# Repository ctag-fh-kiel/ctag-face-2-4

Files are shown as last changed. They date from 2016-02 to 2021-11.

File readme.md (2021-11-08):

CTAG face2|4 Audio Card, based on AD1938 codec
==============================================

This document includes board information, assembly guidelines, extensions and revision remarks, license and authors information.

Board information
-----------------
- 4 layer PCB including ground and power plane
- 10mil tracks offering close to 50Ohms impedance
- Part sizes on board are chosen to allow for hand-soldering 0603 as standard size for resistors etc.
- Used http://kicad.org/ for board design
- Board has 3 logical sections
  - Power supply (digital, analog)
     - Includes separate 3.3V digital supply and 3.3V + 5V analog supply
     - Includes boost converter that allows to run board on dual AA battery pack (3V input)
     - Standard input voltage at P201 should be +5V, see assembly options below
  - Codec including reset circuitry and digital I/O
  - Analog I/O
     - We checked several different single supply rail-to-rail OP Amps, where the cheap TLV272 performed pretty well, similar to the LMV722
- Codec and analog section is mainly based on Analog Devices reference design http://www.analog.com/media/en/technical-documentation/user-guides/UG-087.pdf

Assembly
-------------
- face2|4 BOM shared at Mouser
  - http://www.mouser.com/tools/projectcartsharing.aspx Access ID: 43007b9807
- Start with assembling the power supply sections
  - Several options for configuration are possible
     - A: Simplest possible, assemble only U203, U204, bypass U201 with JP201, bypass L202 with JP206, bypass L203 with JP207, assemble FB202, place JP204. Input voltage can be anything from 6-9V in this configuration.
     - B: No dedicated 3.3V digital do not assemble U202, assemble FB202, input voltage can be anything 2.4V-5V, boost converter will generate 5.5V for low-noise LDOs
     - C: With dedicated 3.3V digital supply, default in schematic, input voltage should be 5V
  - Check if power supply works by observing the LEDs
- Continue with codec, digital I/O and bias circuitry
  - Assembling only C311, C312 + JP301 is enough, using CM bias for test purposes
  - Test codec with microcontroller system, check at R602 R605 for signal output	
- Finally assemble analog section
  - May play around with some different OP amps

Extensions
-------------
- Created cape for Beagle Bone Green / Black including digital isolators to reduce noise (BBG-cape)
- Beagle Board X15 break out adapters for Hirose headers

Revisions
-------------
- face2|4
  - Rev. A2
     - Fixed polarity bug on IN2 at ADC2RP ADC2RN
    - Known Bugs: 
	 - none
	 - Rev. A has polarity bug on IN2
  - Todos for next Rev.
     - Possibly simplify power supply
     - Remove option to choose bias output from codec --> simplify board
	 - Option for balanced inputs
	 - Optimize pins on P1001 to improve routing, i.e. less vias on high speed digital lines, preserve impedance
- BBG-cape
  - Rev. A 
     - Initial Revision
    - Known Bugs: -
- X15 adaptor
  - Rev. A
     - Initial Revision, thanks to Michael Welling for review
	 
License
-------
This work is licensed under the Creative Commons Attribution-NonCommercial-ShareAlike 4.0 International License. 
To view a copy of this license, visit http://creativecommons.org/licenses/by-nc-sa/4.0/.
Anyone re-using this design needs to attribute to authors and http://www.creative-technologies.de website.

Authors
-------
- Robert Manzke (robert.manzke@fh-kiel.de), PCB Design
- Henrik Langer (henrik.langer@student.fh-kiel.de), Component Selection, Driver Development for Beagle Bone Series

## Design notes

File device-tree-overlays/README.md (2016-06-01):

# CTAG-face-2|4 - Device Tree Overlays
There are 3 different device tree overlays for 2, 4 and 8 audio channels.
Instructions for the build process can be found [here](https://github.com/beagleboard/bb.org-overlays).

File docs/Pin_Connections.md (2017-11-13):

## BeagleBone Black/Green <-> CTAG face2|4 Pin Connections 

| CTAG face2&#124;4 Pin Name | CTAG face2&#124;4 Pin No. |BB Black/Green Pin No. | BB Black/Green Mode Name | BB Black/Green Pin Name |
| --- |:---:|:---:| --- | --- |
| DLRCLK | 10 | P9.29 Mode 0 | mcasp0_fsx | SPI1_DO |
| DBCLK | 8 | P9.31 Mode 0 | mcasp0_aclkx | SPI1_SCLK |
| ALRCLK | 7 | P9.27 Mode 0 | mcasp0_fsr | GPIO3_19 |
| ABCLK | 9 | P9.12 Mode 6 | mcasp0_aclkr | GPIO1_28 |
| DSDATA1 | 18 | P9.28 Mode 2 | mcasp0_axr2 | SPI1_CS0 |
| ASDATA1 | 3 | P9.30 Mode 0 | mcasp0_axr0 | SPI1_D1 |
| spi4 | 17 | P9.17 Mode 0 | spi0_cs0 | I2C1_SCL |
| spi3 | 15 | P9.22 Mode 0 | spi0_sclk | UART2_RXD |
| spi2 | 13 | P9.21 Mode 0 | spi0_d0 | UART2_TXD |
| spi1 | 11 | P9.18 Mode 0 | spi0_d1 | I2C1_SDA |
| RESET_IN | 4 | P9.15 Mode 7 | gpio1[16] | GPIO1_16 |

## BeagleBone Black/Green <-> CTAG face2|4 SW SPI Pin Connections 

| CTAG face2&#124;4 Pin Name | CTAG face2&#124;4 Pin No. |BB Black/Green Pin No. | BB Black/Green Mode Name | BB Black/Green Pin Name |
| --- |:---:|:---:| --- | --- |
| DLRCLK | 10 | P9.29 Mode 0 | mcasp0_fsx | SPI1_DO |
| DBCLK | 8 | P9.31 Mode 0 | mcasp0_aclkx | SPI1_SCLK |
| DSDATA1 | 18 | P9.28 Mode 2 | mcasp0_axr2 | SPI1_CS0 |
| ASDATA1 | 3 | P9.30 Mode 0 | mcasp0_axr0 | SPI1_D1 |
| spi5 | TBD | P8.31 Mode 7 | spi_cs1 | GPIO0_10 |
| spi4 | TBD | P8.17 Mode 7 | spi_cs0 | GPIO0_27 |
| spi3 | TBD | P8.32 Mode 7 | spi_clk | GPIO0_11 |
| spi2 | TBD | P8.14 Mode 7 | spi_miso | GPIO0_26 |
| spi1 | TBD | P8.33 Mode 7 | spi_mosi | GPIO0_9 |
| RESET_IN | TBD | P8.34 Mode 7 | gpio2[17] | GPIO2_17 |

For details about the expansion connectors check the [BeagleBone Black System Reference Manual](https://github.com/CircuitCo/BeagleBone-Black/blob/master/BBB_SRM.pdf) p. 82 ff.

## BeagleBoard-X15 <-> CTAG face2|4 Pin Connections

| CTAG face2&#124;4 Pin Name | CTAG face2&#124;4 Pin No. | BB-X15 Pin No. | BB-X15 Pin Name | AM5728 Ball | Muxmode	| Offset | Signal	|
|:--- |:--- |:--- |:--- |:--- |:---|:--- |:---|
| DLRCLK | 10 		 | P17.52 	  | MCASP2_FSX | A18	  | 0		| 0x2F8	 | mcasp2_fsx	|
| DBCLK | 8 		 | P17.21 	  | MCASP2_ACLKX | A19	  | 0		| 0x2F4	 | mcasp2_aclkx	|
| ALRCLK | 7 		 | P17.57 	  | MCASP2_FSR | A20	  | 0		| 0x300	 | mcasp2_fsr	|
| ABCLK | 9 		 | P17.44 	  | MCASP2_ACLKR | E15	  | 0		| 0x2FC	 | mcasp2_aclkr	|
| DSDATA1 | 18 		 | P17.18 	  | MCASP2_AXR2 | C15	  | 0		| 0x30C	 | mcasp2_axr2	|
| ASDATA1 | 3 		 | P17.54 	  | MCASP2_AXR0 | B15	  | 0		| 0x304	 | mcasp2_axr0	|
| spi4	 | 17 		 | P16.3 	  | GPIO4_17	 | A12	  | 3		| 0x2E0	 | spi3_cs0	|
| spi3 | 15 		 | P16.34 	  | GPIO5_10	 | B12	  | 3		| 0x2D4	 | spi3_sclk	|
| spi2 | 13 		 | P16.33 	  | GPIO5_12	 | B13	  | 3		| 0x2DC	 | spi3_d0	|
| spi1 | 11 		 | P16.4 	  | GPIO5_11	 | A11	  | 3		| 0x2D8	 | spi3_d1	|
| RESET_IN | 4 		 | P17.25 	  | GPIO5_9 | D12	  | 14		| 0x2D0	 | gpio5_9	|

For details about the expansion connectors check out the [BeagleBoard-X15 Schematic](https://github.com/beagleboard/beagleboard-x15/blob/master/BeagleBoard-X15_RevA2.pdf?raw=true)
and [AM5728 datasheet](http://www.ti.com/lit/ds/symlink/am5728.pdf).

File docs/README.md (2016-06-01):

# Contents
+ [Quick Start Guide](https://github.com/ctag-fh-kiel/ctag-face-2-4/blob/master/docs/Quick_Start_Guide_Debian_Image.md) for SD Card Image
+ [Kernel Compilation Guide](https://github.com/ctag-fh-kiel/ctag-face-2-4/blob/master/docs/Kernel_Compilation_Guide.md) for BeagleBone Black/Green
+ [Manual](https://github.com/ctag-fh-kiel/ctag-face-2-4/blob/master/docs/Automatic_Evaluation_Manual.md) for Automatic Evaluation
+ BeagleBone Black/Green <-> CTAG face2|4 Audio Card [Pin Connections Table](https://github.com/ctag-fh-kiel/ctag-face-2-4/blob/master/docs/Pin_Connections.md)

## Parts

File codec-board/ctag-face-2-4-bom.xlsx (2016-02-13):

Mouser | Id | Designator | Package | Quantity | Designation | MfrNum | Remarks
x | 1 | C509,C204,C405,C409,C505,C603,C607,C703,C707,C803,C807,C903,C907 | c_elec_6.3x5.7 | 13 | 47uF | EEE-FC1C470P | Panasonic FC Type
x | 2 | C201 | C_0603_HandSoldering | 1 | 33pF | VJ0603A330JXACW1BC
x | 3 | C202 | C_1210_HandSoldering | 1 | 22uF | C3225X7R1C226K250AC | 10% X7R Highest Voltage Type possible
x | 4 | C203,C205,C207,C208,C209,C210,C211,C212,C213,C214,C215,C216 | C_1210_HandSoldering | 12 | 10uF | GRM32DR71E106KA12L | 10% X7R Highest Voltage Type possible
x | 5 | C206 | TantalC_SizeA_EIA-3216_HandSoldering | 1 | 100uF | TCNK107M006R0200
x | 6 | C301,C302,C303,C304,C305,C309,C311,C314,C401,C410,C413,C420,C501,C510,C513,C520,C602,C702,C802,C902 | C_0603_HandSoldering | 20 | 100nF | C0603C104K5RACTU
x | 7 | C306 | C_0603_HandSoldering | 1 | 390pF | GRM1885C1H391JA01D
x | 8 | C307 | C_0603_HandSoldering | 1 | 5,6nF | C0603C562J5GACTU
x | 9 | C308,C313 | C_0603_HandSoldering | 2 | 22pF | C0603C220J5GACTU
x | 10 | C310,C312 | c_elec_4x5.7 | 2 | 10uF | EEE-FC1C100R
x | 11 | C402,C404,C414,C416,C502,C504,C514,C516 | C_0805_HandSoldering | 8 | 10uF | GRM21BR71A106KA73L
x | 12 | C403,C411,C412,C415,C503,C511,C512,C515 | C_0603_HandSoldering | 8 | 100pF | C0603C101J5GACTU
x | 13 | C406,C417,C506,C517,C601,C606,C701,C706,C801,C806,C901,C906 | C_0603_HandSoldering | 12 | 270pF | GRM1885C1H271JA01D
x | 14 | C407,C408,C418,C419,C507,C508,C518,C519 | C_0603_HandSoldering | 8 | 1nF | GCM188R71H102KA37D
x | 15 | C604,C608,C704,C708,C804,C808,C904,C908 | C_0603_HandSoldering | 8 | 200pF | GRM1885C2A201JA01D
x | 16 | C605,C609,C705,C709,C805,C809,C905,C909 | C_0603_HandSoldering | 8 | 3,3nF | C0603C332K5RACTU
x | 17 | D201 | SOD-123 | 1 | D_Schottky | STPS140Z
x | 18 | D203 | LED-1206 | 1 | LED3V3D | SML-LX1206GC-TR1
x | 19 | D204 | LED-1206 | 1 | LED3V3A | SML-LX1206GC-TR1
x | 20 | D205 | LED-1206 | 1 | LED5VA | SML-LX1206GC-TR1
x | 21 | JP201,JP206,JP207 | R_0805_HandSoldering | 3 | Jumper_NO_Small | RC0805JR-070RL
x | 22 | JP203,JP204,JP301,JP302 | R_0603_HandSoldering | 4 | Jumper_NO_Small | ERJ-3GEY0R00V
x | 23 | R201 | R_0603_HandSoldering | 1 | 115k | ERJ-3EKF1153V | Resistors all probably 1%, except digital section
x | 24 | R202,R303 | R_0603_HandSoldering | 2 | 1M | ERJ-3EKF1004V
x | 25 | R203 | R_0603_HandSoldering | 1 | 32k4 | ERJ-3EKF3242V
x | 26 | R204,R206 | R_0603_HandSoldering | 2 | 270 | ERJ-3EKF2700V
x | 27 | R205,R207,R302,R305,R408,R409,R508,R509,R604,R608,R704,R708,R804,R808,R904,R908 | R_0603_HandSoldering | 16 | 100k | ERJ-3EKF1003V
x | 28 | R208 | R_0603_HandSoldering | 1 | 620 | ERJ-3EKF6200V
x | 29 | R301 | R_0603_HandSoldering | 1 | 562 | ERJ-3EKF5620V
x | 30 | R304 | R_0603_HandSoldering | 1 | 100 | ERJ-3EKF1000V
x | 31 | R401,R402,R410,R411,R501,R502,R510,R511 | R_0603_HandSoldering | 8 | 237 | ERJ-3EKF2370V
x | 32 | R403,R404,R405,R406,R407,R412,R413,R414,R503,R504,R505,R506,R507,R512,R513,R514,R601,R602,R605,R606,R701,R702,R705,R706,R801,R802,R805,R806,R901,R902,R905,R906 | R_0603_HandSoldering | 32 | 5k36 | ERJ-3EKF5361V
x | 33 | R603,R607,R703,R707,R803,R807,R903,R907 | R_0603_HandSoldering | 8 | 301 | ERJ-3EKF3010V
x | 34 | R1001,R1002,R1003,R1004,R1005,R1006,R1007,R1008,R1009,R1010 | R_0603_HandSoldering | 10 | 51 | ERJ-3EKF51R0V
x | 35 | SW301 | SW_SPST_PTS645 | 1 | SW_PUSH | PTS645SM43SMTR 92 LFS
x | 36 | U201 | MSOP-8_3x3mm_Pitch0.65mm | 1 | MCP1642B-ADJI/MS | MCP1642B-ADJI/MS
x | 37 | U202 | SOT-223 | 1 | TLV1117 | TLV1117-33IDCYR
x | 38 | U203 | SOIC-8_3.9x4.9mm_Pitch1.27mm | 1 | ADP7102ARDZ-3.3-R7 | ADP7102ARDZ-3.3-R7
x | 39 | U203,U204 | SOIC-8_3.9x4.9mm_Pitch1.27mm | 1 | ADP7102ARDZ-5.0-R7 | ADP7102ARDZ-5.0-R7
x | 40 | U301 | LQFP-48_7x7mm_Pitch0.5mm | 1 | AD1938 | AD1938YSTZ
x | 41 | U302 | SOT-143 | 1 | ADM811TARTZ | ADM811TARTZ-REEL7
x | 42 | U401,U402,U501,U502,U601,U701,U801,U901 | SOIC-8_3.9x4.9mm_Pitch1.27mm | 8 | 2CH-OPAMP | LME49721MAX/NOPB
x | 43 | Y301 | Q_49U3HMS | 1 | 24,576MHz | AT-24.576MAGK-T | Alternative
x | 44 | Y301 | Q_49U3HMS | 1 | 12,288MHz | AT-12.288MAGE-T
x | 45 | D202 | Diode-Universal-SMA-SMB_Handsoldering | 1 | FM4002 | FM4002
x | 46 | FB201,FB203 | R_0805_HandSoldering | 2 | 330R | 742792037 | Würth Beads
x | 47 | FB202 | R_0805_HandSoldering | 1 | 600R | 742792040
x | 48 | L201,L202,L203 | LPS4018 | 3 | 4.7uH | LPS4018-472MRC
x | 49 | P307 | DIL Socket 4+4 | 1 | ~ | M20-7830446 (https://www.mouser.de/Search/ProductDetail.aspx) | Reichelt
x | 50 |  | Stiftleiste 40 Pins RM2,54 | 1 |  | M20-9734045 (https://www.mouser.de/Search/ProductDetail.aspx)
x | 51 |  | DIL Socket 10+10 | 1 |  | M20-7831046 (https://www.mouser.de/Search/ProductDetail.aspx)
x | 52 | C207, C208, C213, C214 | Alternative Configuration | 4 | 1uF | GRM32RR71H105KA01L | Configuration according to data sheet of ADPxxx
x | 53 | R604, R608 etc. | Alternative Configuration | 8 | 49k9 | ERJ-3EKF4992V

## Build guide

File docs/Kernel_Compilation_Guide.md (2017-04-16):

# BeagleBone Green/Black Kernel Compilation Guide

*The build instructions were tested on Ubuntu 14.04.*

+ Install build tools
```bash
sudo apt-get install git lzop libssl-dev libncurses5-dev wget u-boot-tools git
```
+ Clone Git repository of forked Linux kernel
```bash
git clone https://github.com/henrix/beagle-linux.git && cd beagle-linux
```
+ Download hard float linearo compiler
```bash
wget https://releases.linaro.org/components/toolchain/binaries/5.4-2017.01/arm-linux-gnueabihf/gcc-linaro-5.4.1-2017.01-x86_64_arm-linux-gnueabihf.tar.xz
tar xf gcc-linaro-5.4.1-2017.01-x86_64_arm-linux-gnueabihf.tar.xz
```
+ Clean build directory and create temporary directory
```bash
make mrproper && mkdir modules_tmp
```
+ Generate kernel config
```bash
make ARCH=arm CROSS_COMPILE=gcc-linaro-5.4.1-2017.01-x86_64_arm-linux-gnueabihf/bin/arm-linux-gnueabihf- bb.org_defconfig
```
+ Enable driver for CTAG face2|4 Audio Card (→ Device Drivers → Sound card support → Advanced Linux Sound Architecture → ALSA for SoC audio support → SoC Audio Support for CTAG face-2-4 Audio Card (AD1938))
```bash
make ARCH=arm CROSS_COMPILE=gcc-linaro-5.4.1-2017.01-x86_64_arm-linux-gnueabihf/bin/arm-linux-gnueabihf- menuconfig
```
+ Compile the kernel
```bash
make ARCH=arm CROSS_COMPILE=gcc-linaro-5.4.1-2017.01-x86_64_arm-linux-gnueabihf/bin/arm-linux-gnueabihf- -j9
```
+ Compile device tree blobs
```bash
make ARCH=arm CROSS_COMPILE=gcc-linaro-5.4.1-2017.01-x86_64_arm-linux-gnueabihf/bin/arm-linux-gnueabihf- dtbs -j9
```
+ Compile kernel modules
```bash
make ARCH=arm CROSS_COMPILE=gcc-linaro-5.4.1-2017.01-x86_64_arm-linux-gnueabihf/bin/arm-linux-gnueabihf- modules -j9
```
+ Install compiled kernel and modules to temporary directory
```bash
make ARCH=arm CROSS_COMPILE=gcc-linaro-5.4.1-2017.01-x86_64_arm-linux-gnueabihf/bin/arm-linux-gnueabihf- INSTALL_MOD_PATH=modules_tmp modules_install
```
+ Copy kernel image to SD card
```bash
sudo cp arch/arm/boot/zImage /media/$USER/rootfs/boot/vmlinuz-4.1.18+
```
+ Copy kernel modules to SD card
```bash
sudo cp -r modules_tmp/lib/ /media/$USER/rootfs/
```
+ Copy device tree blobs to SD card
```bash
sudo mkdir -p /media/$USER/rootfs/boot/dtbs/4.1.18+ && cp -r arch/arm/boot/dts/*.dtb /media/$USER/rootfs/boot/dtbs/4.1.18+/
```
+ Copy kernel configuration to SD card
```bash
sudo cp .config /media/$USER/rootfs/boot/config-4.1.18+
```
## The next steps must be executed directly on the BeagleBone Black/Green
+ Insert the following line into **/boot/uEnv.txt** to use the new kernel
```bash
uname_r=4.1.18+
```
+ Insert the following line into **/boot/uEnv.txt** to use the custom device tree blob
```bash
dtb=am335x-bonegreen-ctag-face.dtb
```
+ Reboot to use new kernel
```bash
reboot
```
+ Generate initramfs image and reboot again
```bash
sudo update-initramfs -c -k $(uname -r)
reboot
```
+ Clone CTAG face2|4 AudioCard repo
```bash
git clone https://github.com/ctag-fh-kiel/ctag-face-2-4.git && cd ctag-face-2-4/device-tree-overlays
```
+ Compile Device Tree Overlays for CTAG face2|4 Audio Card
```bash
dtc -O dtb -o BB-CTAG-FACE-8CH-00A0.dtbo -b 0 -@ BB-CTAG-FACE-8CH-00A0.dts
sudo mv BB-CTAG-FACE-8CH-00A0.dtbo /lib/firmware
```
+ Load kernel modules for CTAG face2|4 Audio Card with Bone-Cape-Manager
```bash
sudo sh -c "echo 'BB-CTAG-FACE-8CH' > /sys/devices/platform/bone_capemgr/slots"
```

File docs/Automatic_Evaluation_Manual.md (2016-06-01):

# Manual for Automatic Evaluation

## Test Prerequisites
+ ADC1 needs to be connected with DAC1 (loopback)
+ GNU Octave Version>3.8 (already installed on SD card image)

## Description
The automatic evaluation is made up of 4 single tests for:

1. Latency (took from [alsa-lib](http://www.alsa-project.org/alsa-doc/alsa-lib/_2test_2latency_8c-example.html))
2. THD, THD+N, DNR
3. Crosstalk
4. Frequency Response

The test scripts and sample files are located in the directory **/home/debian/automated_test** on the SD card image.<br>
The automatic evaluation can be executed by running
```bash
automated_test.sh
```
from the home directory of user "debian".

## BASH script parameters
1. ALSA Playback Device (e.g. hw:0)
2. ALSA Capture Device
3. Name of soundcard to be tested (will be used in spectrum plots)
4. *Name of single test (latency, thd, crosstalk, frequency-response) (optional)*

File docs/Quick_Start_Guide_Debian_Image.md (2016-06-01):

# Quick Start Guide for SD Card Image 
## SD Card Preparation
1. Download [Debian Wheezy SD card image](https://drive.google.com/file/d/0B2goLqs_HZ3QMFV4SFNySjJzX3M/view?usp=sharing)
2. Install Debian image on SD card (see [Raspberry Pi Guide](https://www.raspberrypi.org/documentation/installation/installing-images/README.md))

## Debian Configuration of SD Card Image
### Login 
Username: debian <br>
Password: temppwd

### Global Soundcard Configuration
The required kernel modules will be loaded automatically at boot time (see /etc/rc.local).<br>
By default the soundcard is configured to use 4 input channels and 8 output channels.<br>
If a higher sampling rate of 192 kHz is needed, the soundcard can be configured to use only 4 output channels.<br>
(Change line 22 in /etc/rc.local<br>**sh -c "echo 'BBB-AD193X-8TDM' > /sys/devices/platform/bone_capemgr/slots"** to<br>**sh -c "echo 'BBB-AD193X-4TDM' > /sys/devices/platform/bone_capemgr/slots"**)<br>
The global ALSA configuration /etc/asound.conf contains routings to interact with single ADCs and DACs (ADC1 - ADC2, DAC1 - DAC4)

### Soundcard Control
The multichannel soundcard can be controlled with the ALSA tools "alsamixer" or "amixer".
alsamixer has a dialog based GUI and is simpler, but amixer is more detailed.
The soundcard offers different playback de-emphasis modes, ADC high pass filter configuration and volume controls for single ADCs and DACs.

### Automatic Evaluation
The scripts for the automatic evaluation of the audio system are located in /home/debian/automated_test.
The results will be saved in /home/debian/automated_test/results.
See the [Manual for Automatic Evaluation](https://github.com/ctag-fh-kiel/ctag-face-2-4/blob/master/docs/Automatic_Evaluation_Manual.md) for more details.

### Demo Surround-Delay Audio Effect
The Surround-Delay effect can be executed by running the following command from the home directory of user "debian":
```bash
./delay.sh
```

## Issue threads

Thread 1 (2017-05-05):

Kernel compilation error

Eldarosaurus, 2017-05-05:
I'm trying to compile the kernel for a Beaglebone Black Wireless on a Ubuntu 14.04 machine. When trying to compile the kernel I get this error:

Makefile:660: Cannot use CONFIG_CC_STACKPROTECTOR_STRONG: -fstack-protector-strong not supported by compiler

Any ideas on what is going wrong?

I've also tried the quick setup SD image, but my Beaglebone Black Wireless won't boot with that image...

henrix, 2017-05-06:
Did you use a recent version of Linaro compiler (see [here](https://github.com/ctag-fh-kiel/ctag-face-2-4/blob/master/docs/Kernel_Compilation_Guide.md)).
Furthermore, the driver is already included in the official BeagleBoard.org images, so you don't have to compile the kernel on yourself.

Eldarosaurus, 2017-05-06:
So if I install an official BeagleBoard.org image, I can use the functions of the AD1938 out of the box with the commands described on this repository?

Is that correct?

henrix, 2017-05-07:
Have you generated a buildconfig (bb.org_defconfig) before compilation?
I just checked it and I don't get those errors.

Yes, after you flashed a recent image to a SD-card, you have to set the base device tree in /boot/uEnv.txt (dtb=am335x-bonegreen-ctag-face.dtb) and compile the appropriate device tree overlay (e.g. BB-CTAG-FACE-8CH-00A0.dts) from this repo using device tree compiler (e.g. dtc -O dtb -o BB-CTAG-FACE-8CH-00A0.dtbo -b 0 -@ BB-CTAG-FACE-8CH-00A0.dts) and move it to /lib/firmware as described in the [kernel compilation guide](https://github.com/ctag-fh-kiel/ctag-face-2-4/blob/master/docs/Kernel_Compilation_Guide.md).

Then you can simply load the overlay and the soundcard is showed up with aplay -l.

Eldarosaurus, 2017-05-08:
Yes I did, I just repeated all of the steps and at one point I got a prompt to install this thing: 'sudo apt-get install tor-arm', which I did. Then I ran the entire routine again and surely the error message was gone on the first compilation command, but afterwards, my terminal started throwing other errors. For future reference/improvement/fixing I'll attach the full terminal conversation to this post, but at this time, I'll be moving on using an official BeagleBoard.org image.

[Full output.txt](https://github.com/ctag-fh-kiel/ctag-face-2-4/files/983086/Full.output.txt)

Closed 2017-05-08.

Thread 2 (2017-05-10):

Beaglebone Black Wireless fails to boot after custom device tree blob change

Eldarosaurus, 2017-05-10:
Let's start this issue where the other one ended: I'm trying to get the AD1938 working with a BeagleBone Black Wireless. I flashed the BBBW with a recent official BBBW image and tried to use the custom device tree blob presented in this repository. However after changing uEnv.txt my BBBW refuses to boot.

When adding/substituting (I tried both) this line:
`dtb=am335x-bonegreen-ctag-face.dtb`
The BBB won't boot and gets stuck with the usr0 led blinking

I get the same thing when using the given quick start image by the way.

When adding/substituting (I tried both) this line as well as the above:
`uname_r=4.1.18+`
The BBB won't boot and gets stuck with all usr leds on forever.

I first tried to do these adaptations with the OS on the SD-card. Then I also tried to copy the OS to the internal memory first and then doing the adaptations, but (as expected) no change there, so that's not the issue.

Any ideas on what's going wrong?
How long should I wait with the led blinking until giving up, my last attempt ran for an hour and a half... What's the booting time of a working solution?

henrix, 2017-05-11:
I think this is caused from the device tree.
I will create a new device tree for the BeagleBone Black Wireless the next days, but unfortunately I don't have a BBB Wireless for testing.

I will update this thread then and hope it works.

Moreover I will create a stable 4.4 branch and move my active development for the daisy chained driver to a dedicated branch.

Eldarosaurus, 2017-05-11:
That's very good news.

I'll be using a BeagleBone Black (non Wireless) in the meantime - or do you recommend the Green?

(To clarify: I'm using an AD1938 as a part of my master's thesis and I'm trying to find a good platform to demo my hardware ;) )

henrix, 2017-05-12:
You could use the Black or Green.
Both are working fine.

Glad to hear that you use our platform;)

Eldarosaurus, 2017-05-23:
Hi, I've tried both the Black and Green but to no avail.

The quick start image still won't boot and when using a beagleboard.org image, the black behaves in the same way as the black wireless and the green won't even boot with the unmodified image. Surely I must be doing something wrong. Could you give a more detailed description of the steps that need to be taken? I hope I'm making a small mistake here ;)

henrix, 2017-05-23:
Hi,

I have created a [new image](https://drive.google.com/file/d/0B2goLqs_HZ3QRXdhWno2cUsta0U/view?usp=sharing) last week. You don't have to change anything, to use it with the AD1938 codec.

On the official images, you have to:
1. Edit the dtb= line in the uEnv.txt file and change it to am335x-boneblack-ctag-face.dtb or am335x-bonegreen-ctag-face.dtb
2. Compile the device tree overlay (either the overlays for software SPI or hardware SPI) and load it via the Bone Capemanager

> How do you interface with the boards: USB, Ethernet, HDMI & Keyboard (in the case of the BBB)...?

I personally use the virtual Ethernet via USB and ssh due to flexibility.

> When used with USB, which computer do you use? (I've tried on a windows laptop and a macbook)

I'm using a Linux distribution. If you want to use Windows or Mac OS, you have to [install the drivers](http://beagleboard.org/getting-started) for virtual Ethernet.

> When used with ethernet, are there special connection steps to be taken?

The Ethernet port of the BB is configured to use an automatically assigned IP. So you need a DHCP server.

> When used with HDMI, does your BBB give a terminal window when connected to a screen?

I don't use HDMI. In our device tree, HDMI is disabled, as well.

> How long does it take for the quickstart image to boot?

It should be around 20 seconds (depends if you are using a GUI or running the BB headless). Moreover there are some performance optimizations available.

> Update: when using the quickstart image on SD in a BBB, connected via Ethernet, my windows computer's network troubleshooter says that "Ethernet does not have a valid IP configuration"

You don't have a DHCP server running. You can try [this one](http://www.dhcpserver.de/cms/) on Windows.

Eldarosaurus, 2017-05-24:
Thanks for the answers!

I've been trying and searching around and here's where I am now:
I did install all drivers but the DHCP seems to do things beyond my comprehension...

- On windows, I installed a DHCP server and I do get a connection, but when I try to ssh to the given IP address with putty, I get a connection timed out error, I also tried the default IP adresses, but to no good
- On linux (Ubuntu 14.04) , two Beaglebone virtual ethernet connections are active, but the same problem, I can't find the right IP address, tried nmap for a ton of addresses, but no luck there...

Which brings me to the next question:

Given that the Beaglebone gets it's IP address dynamically with DHCP, where can I find the right IP address for SSH? Or what's the name of the BBB for SSH (e.g. ssh debian@beaglebone doesn't work)?

Many thanks!

henrix, 2017-05-24:
The Ethernet port of the BeagleBone is configured to use a DHCP server by default.
The virtual Ethernet port via USB of the BeagleBone has a static IP (192.168.7.2) and should assign 192.168.7.1 to the virtual Ethernet port of your host PC.
So, when using the virtual Ethernet via USB, you should be able to ssh into your BeagleBone with `ssh debian@192.168.7.2` and the default password "temppwd".

Eldarosaurus, 2017-05-25:
Unfortunately, when connected with USB, all platform give a connection timeout for `ssh debian@192.168.7.2`. But I cracked it on windows. After setting up my DHCP server, I went into the networks and sharings center and changed the IP address for the windows computer for communicating via ipv4 to 192.168.7.1.

 https://www.youtube.com/watch?v=D-NEPiZDSx8 → it's shown in the middle of the video

Thanks for all the help :) let's hope I get everything running now :)

Closed 2017-05-25.

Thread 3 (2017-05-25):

Capture channels in amixer

Eldarosaurus, 2017-05-25:
I've made great progress :)

My custom hardware gets recognised, but the amixer command yields some surprising settings.

How are the capture channels configured? I'm getting two ADC's as expected, but they seem to be configured as playback channels and the four DAC channels seem to be configured as both playback and capture channels.

Is this normal?

Also, all inputs and outputs seem to be permanently off, I've tried changing this with numid cset ... but my commands seem to be ignored... What is the regular way to make these work? Might be a fault in my hardware too ;)

henrix, 2017-05-25:
Yes, that's a bit strange of alsamixer, but you can ignore it.
You can unmute the single ADCs and DACs with amixer (e.g. amixer -c 0 sset DAC1 on).

Eldarosaurus, 2017-05-27:
So should I ignore the playback/capture labels of the ADC1 en ADC2 and record using the DAC capture thingies?

Eldarosaurus, 2017-05-28:
Also do you recognise this error:

`arecord: pcm_read:2031: read error: Input/output error` when trying to record...

+ When I try to activate an ADC or a DAC, my command is processed, my terminal shows that the switch is on, but when I run `amixer` again, it's already back off again... Has this happened to you at some point?

henrix, 2017-05-29:
Ignore the playback/capture labels. The names are correct (e.g. ADC1 corresponds to the first hardware ADC). Maybe you have some SPI issues. You can check the kernel logs (my driver logs the register contents of the codec) for verification.

Eldarosaurus, 2017-05-29:
I am indeed having SPI connection issues, I hooked the board up to an oscilloscope and the SPI lines are all high (except the Cout one, which is 0), but no commands are executed, no matter which command I run, the lines stay high. Are there additional steps to be taken to activate the SPI-connection? Something with pin modes? I'm pretty new to linux... I'll take a look at those kernel logs.

henrix, 2017-05-30:
No, the pin modes are configured with the device tree overlay. Do you use the hardware SPI interface or software spi (spi-gpio)? If you playback or capture something, there should be something happening on the SPI interface (e.g. speaker-test).

Eldarosaurus, 2017-05-30:
My SPI wires are connected to pins 17, 18, 21 and 22, so I guess I'm using hardware SPI. (Right?) I'm trying to write to the SPI port now using Adafruit_BBIO, just to see if I can connect to the codec.

Eldarosaurus, 2017-05-30:
The kernel log revealed these errors:

`May  7 14:48:06 beaglebone kernel: [ 1105.814310] bone_capemgr bone_capemgr: part_number 'BB-CTAG-SW-8CH', version 'N/A'
May  7 14:48:06 beaglebone kernel: [ 1105.814362] bone_capemgr bone_capemgr: slot #4: override
May  7 14:48:06 beaglebone kernel: [ 1105.814386] bone_capemgr bone_capemgr: Using override eeprom data at slot 4
May  7 14:48:06 beaglebone kernel: [ 1105.814412] bone_capemgr bone_capemgr: slot #4: 'Override Board Name,00A0,Override Manuf,BB-CTAG-$
May  7 14:48:06 beaglebone kernel: [ 1105.840617] bone_capemgr bone_capemgr: slot #4: dtbo 'BB-CTAG-SW-8CH-00A0.dtbo' loaded; overlay i$
May  7 14:48:06 beaglebone kernel: [ 1105.938200] spi_gpio spi_gpio: can't setup spi32766.0, status -16
May  7 14:48:06 beaglebone kernel: [ 1105.944462] spi_master spi32766: spi_device register error /spi_gpio/ad193x@0
May  7 14:48:06 beaglebone kernel: [ 1105.966636] snd_ctag_face_2_4 ocp:sound: using only one audio codec (no daisy chain).
May  7 14:48:06 beaglebone kernel: [ 1105.966730] snd_ctag_face_2_4 ocp:sound: mclk not found.
May  7 14:48:06 beaglebone kernel: [ 1105.966786] snd_ctag_face_2_4 ocp:sound: ASoC: CODEC DAI ad193x-hifi not registered
May  7 14:48:06 beaglebone kernel: [ 1105.974688] snd_ctag_face_2_4 ocp:sound: snd_soc_register_card failed (-517)
May  7 14:48:06 beaglebone kernel: [ 1106.024593] spi_master spi32766: Failed to create SPI device for /spi_gpio/ad193x@0
May  7 14:48:06 beaglebone kernel: [ 1106.066220] snd_ctag_face_2_4 ocp:sound: using only one audio codec (no daisy chain).
May  7 14:48:06 beaglebone kernel: [ 1106.066314] snd_ctag_face_2_4 ocp:sound: mclk not found.
May  7 14:48:06 beaglebone kernel: [ 1106.066373] snd_ctag_face_2_4 ocp:sound: ASoC: CODEC DAI ad193x-hifi not registered
May  7 14:48:06 beaglebone kernel: [ 1106.074249] snd_ctag_face_2_4 ocp:sound: snd_soc_register_card failed (-517)`

Any idea?

Eldarosaurus, 2017-05-30:
The kernel log revealed some errors..

`May  7 14:48:06 beaglebone kernel: [ 1105.814310] bone_capemgr bone_capemgr: part_number 'BB-CTAG-SW-8CH', version 'N/A'`
`May  7 14:48:06 beaglebone kernel: [ 1105.814362] bone_capemgr bone_capemgr: slot #4: override`
`May  7 14:48:06 beaglebone kernel: [ 1105.814386] bone_capemgr bone_capemgr: Using override eeprom data at slot 4`
`May  7 14:48:06 beaglebone kernel: [ 1105.814412] bone_capemgr bone_capemgr: slot #4: 'Override Board Name,00A0,Override Manuf,BB-CTAG-$`
`May  7 14:48:06 beaglebone kernel: [ 1105.840617] bone_capemgr bone_capemgr: slot #4: dtbo 'BB-CTAG-SW-8CH-00A0.dtbo' loaded; overlay i$`
`May  7 14:48:06 beaglebone kernel: [ 1105.938200] spi_gpio spi_gpio: can't setup spi32766.0, status -16`
`May  7 14:48:06 beaglebone kernel: [ 1105.944462] spi_master spi32766: spi_device register error /spi_gpio/ad193x@0`
`May  7 14:48:06 beaglebone kernel: [ 1105.966636] snd_ctag_face_2_4 ocp:sound: using only one audio codec (no daisy chain).`
`May  7 14:48:06 beaglebone kernel: [ 1105.966730] snd_ctag_face_2_4 ocp:sound: mclk not found.`
`May  7 14:48:06 beaglebone kernel: [ 1105.966786] snd_ctag_face_2_4 ocp:sound: ASoC: CODEC DAI ad193x-hifi not registered`
`May  7 14:48:06 beaglebone kernel: [ 1105.974688] snd_ctag_face_2_4 ocp:sound: snd_soc_register_card failed (-517)`
`May  7 14:48:06 beaglebone kernel: [ 1106.024593] spi_master spi32766: Failed to create SPI device for /spi_gpio/ad193x@0`
`May  7 14:48:06 beaglebone kernel: [ 1106.066220] snd_ctag_face_2_4 ocp:sound: using only one audio codec (no daisy chain).`
`May  7 14:48:06 beaglebone kernel: [ 1106.066314] snd_ctag_face_2_4 ocp:sound: mclk not found.`
`May  7 14:48:06 beaglebone kernel: [ 1106.066373] snd_ctag_face_2_4 ocp:sound: ASoC: CODEC DAI ad193x-hifi not registered`
`May  7 14:48:06 beaglebone kernel: [ 1106.074249] snd_ctag_face_2_4 ocp:sound: snd_soc_register_card failed (-517)`

Eldarosaurus, 2017-05-30:
The kernel log did reveal some errors, they are in the image below...

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

henrix, 2017-05-30:
Have a look in the [pin connections table](https://github.com/ctag-fh-kiel/ctag-face-2-4/blob/master/docs/Pin_Connections.md). You are using the hardware SPI interface, so you have to use the [BB-CTAG-FACE-8CH overlay](https://github.com/ctag-fh-kiel/ctag-face-2-4/blob/master/device-tree-overlays/BB-CTAG-FACE-8CH-00A0.dts).

Eldarosaurus, 2017-05-30:
Right! And I'm trying to load the SW-overlay. Well that wouldn't work indeed.

Well, I just tried changing that, but when running

`sudo sh -c "echo 'BB-CTAG-FACE-8CH' > /sys/devices/platform/bone_capemgr/slots"`

This error comes up:

sh: echo: I/O error

Or am I doing that wrong? When I rebooted, the BB still tried to load the SW-overlay.

Or should I just change the pin configuration I'm using to the other one? In that case, what is the difference between spi4 and spi5?

Eldarosaurus, 2017-05-30:
Oh, I fixed the error, I had to remove the SW-overlay first in capemgr:

`sudo sh -c "echo '-4' > /sys/devices/platform/bone_capemgr/slots"`

henrix, 2017-05-30:
I think there is any issue in the Cape manager. If you are using my image, you should disable the automatic loading of the SW SPI overlay and load the BB-CTAG-FACE-8CH instead.

Eldarosaurus, 2017-05-30:
I've tried to do so, but my changes seem to be reversed immediately... Is my code in the previous messages correct?

henrix, 2017-05-30:
You remove overlays from the Cape manager with your code above.
Have a look in /etc/rc.local and change `BB-CTAG-SW-8CH` to `BB-CTAG-FACE-8CH`.

Eldarosaurus, 2017-05-30:
Well, I did those things now, the good news is: when running `cat /sys/devices/platform/bone_capemgr/slots`, BB-CTAG-SW-8CH is no longer loaded at boot.

The bad news is: BB-CTAG-FACE-8CH doesn't load in int's place and in the kernel logs, the errors remain the same

henrix, 2017-05-30:
Ok, can you please show your kernel logs regarding the sound drivers?

Eldarosaurus, 2017-05-31:
It works!

It was a hardware thing. I was searching around in the lab and found that the PCB track connected to the PD/RST pin was broken. I fixed it and now the interface works :)

Many thanks for the help!

But before closing the subject entirely, I'm recording, I turned on the ADC's but the recorded file is still empty, it must be something small, I measured my codec's inputs and I'm putting a 440 Hz wave on there..

Eldarosaurus, 2017-05-31:
Oddly enough, in the kernel logs, the BB is still trying to lode the software overlay

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

Eldarosaurus, 2017-05-31:
This is the kern.log file for my last bootup

[log.txt](https://github.com/ctag-fh-kiel/ctag-face-2-4/files/1041379/log.txt)

henrix, 2017-05-31:
The issue with the several files is regarded to alsalib. Have a look [here](https://superuser.com/questions/583826/recording-using-arecord-creates-thousands-of-files) how to avoid this.

Closed 2018-02-09.

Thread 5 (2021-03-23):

Different board designs?

resynth, 2021-03-23:
I'm trying to work out how to setup a CTAG face cape (as sold by Bela) in a non-standard way.  As my enclosure does not have space to stack the boards I wish to mount side by side with connectors between the headers of the Beaglebone Black and the headers of the CTAG face cape.  To do this I require a pin out or schematic for the CTAG face.
The CTAG hackaday page directed me here but after getting confused over the schematic it seems the files here relate to a different board or an older revision.  Is that the case?
I've been looking but this github repo is all I can find, are the drawings for the newer board somewhere else or are they closed source?

ctag-fh-kiel, 2021-03-23:
You can find it here: https://github.com/ctag-fh-kiel/bela-ctag

resynth, 2021-03-23:
Brilliant, thankyou

Closed 2021-06-10.

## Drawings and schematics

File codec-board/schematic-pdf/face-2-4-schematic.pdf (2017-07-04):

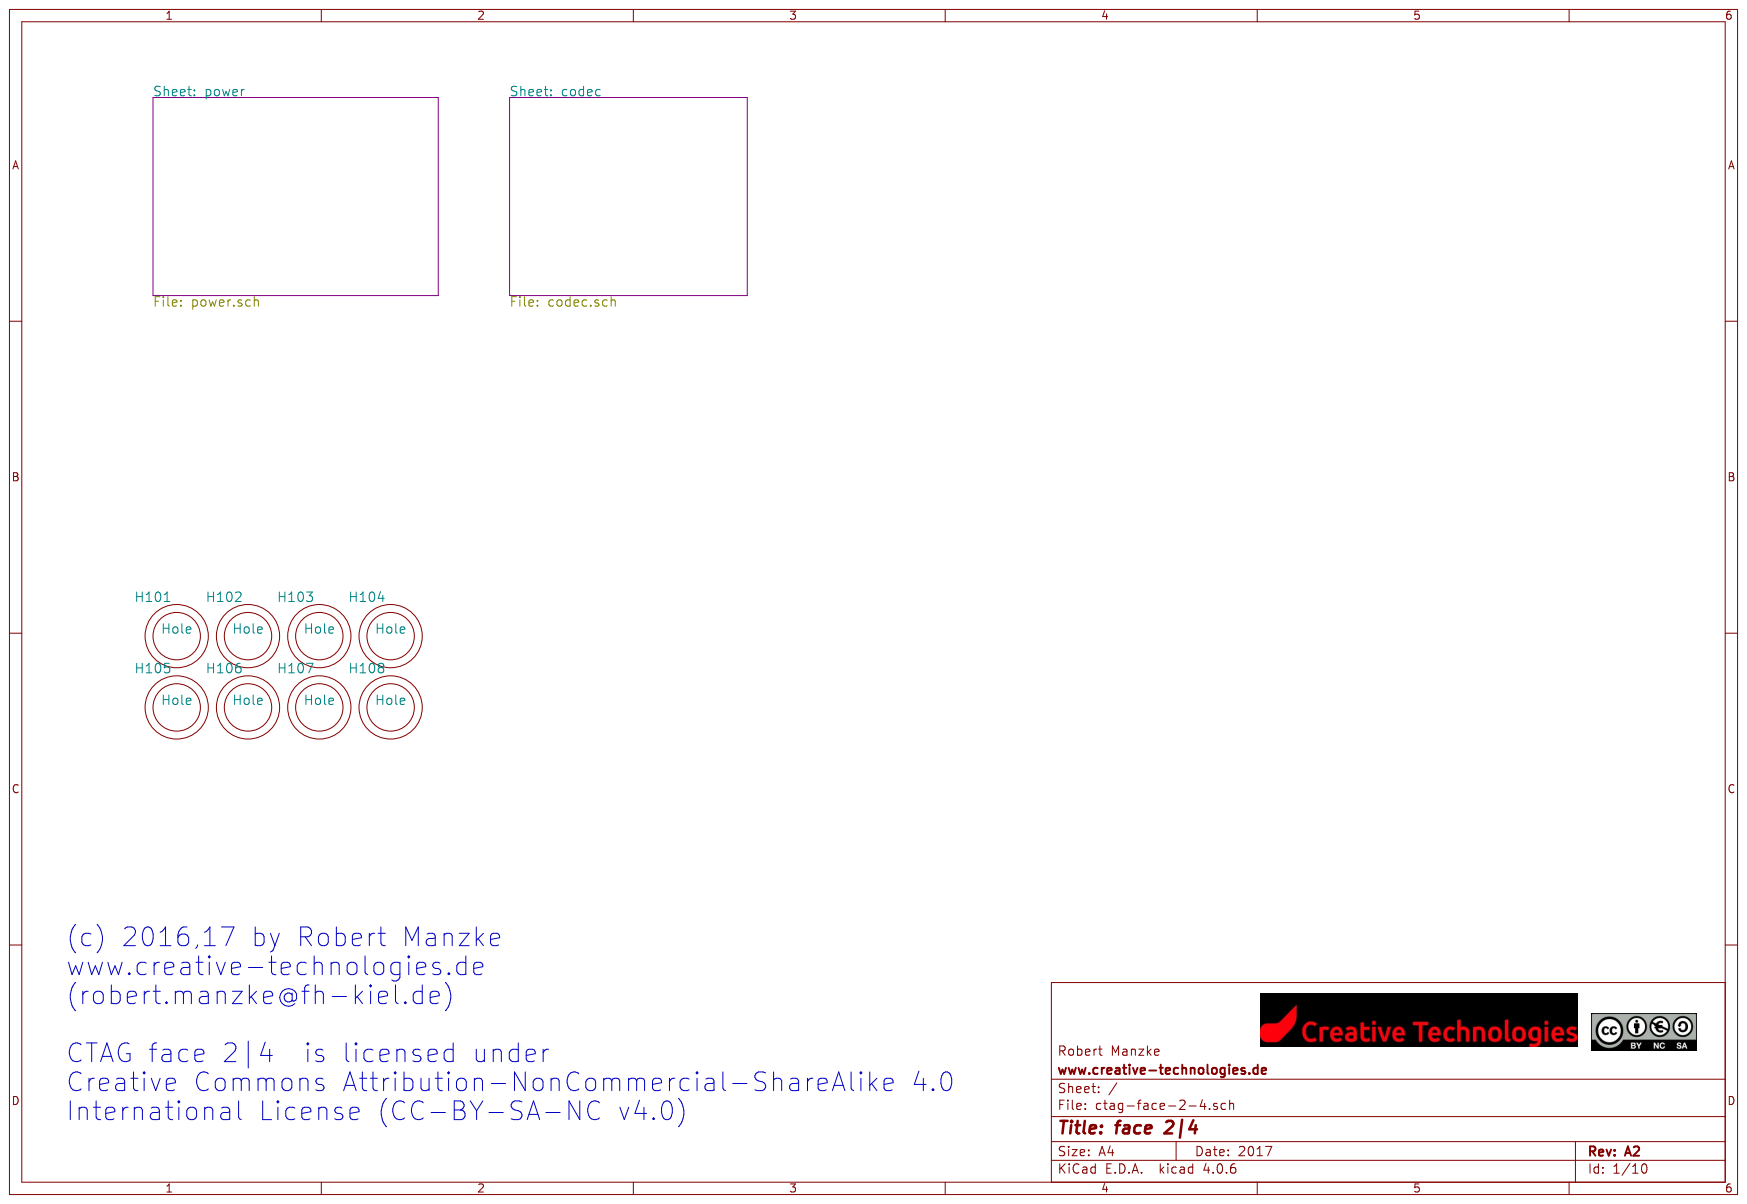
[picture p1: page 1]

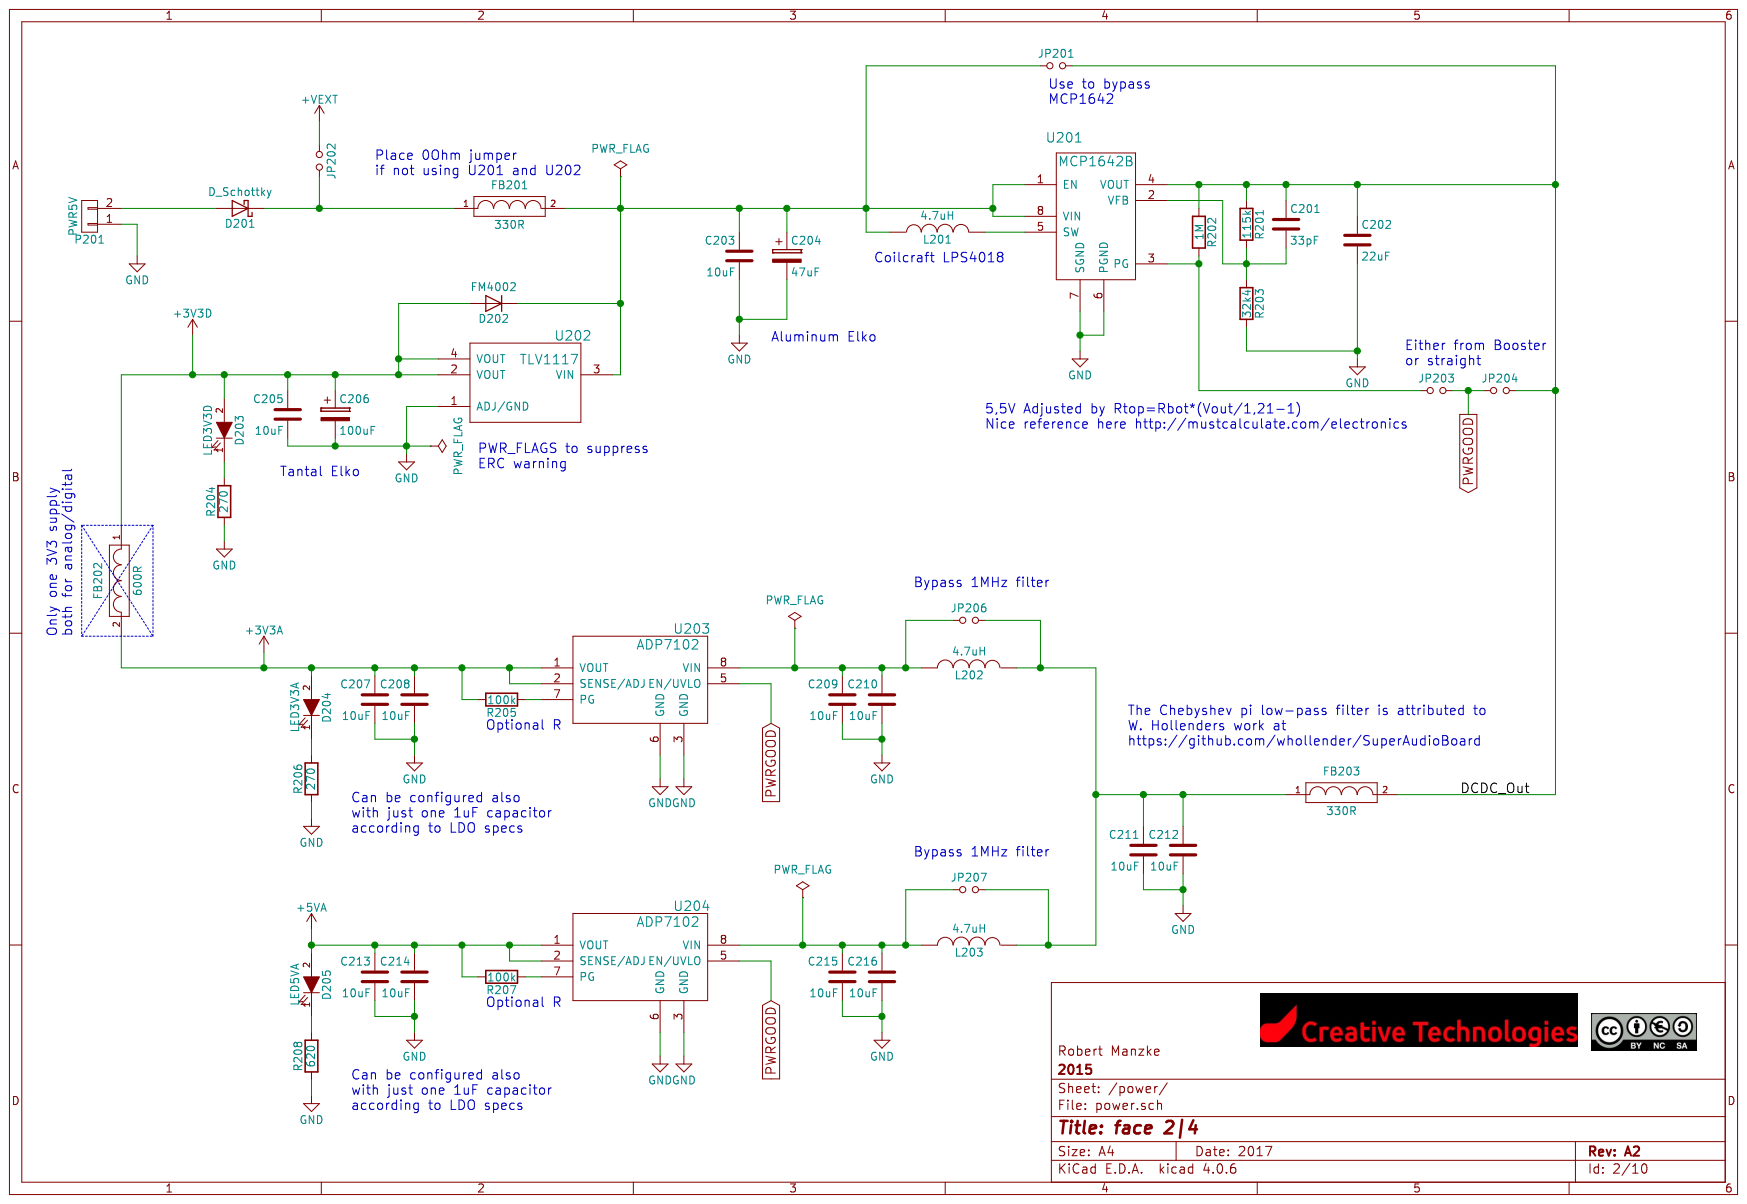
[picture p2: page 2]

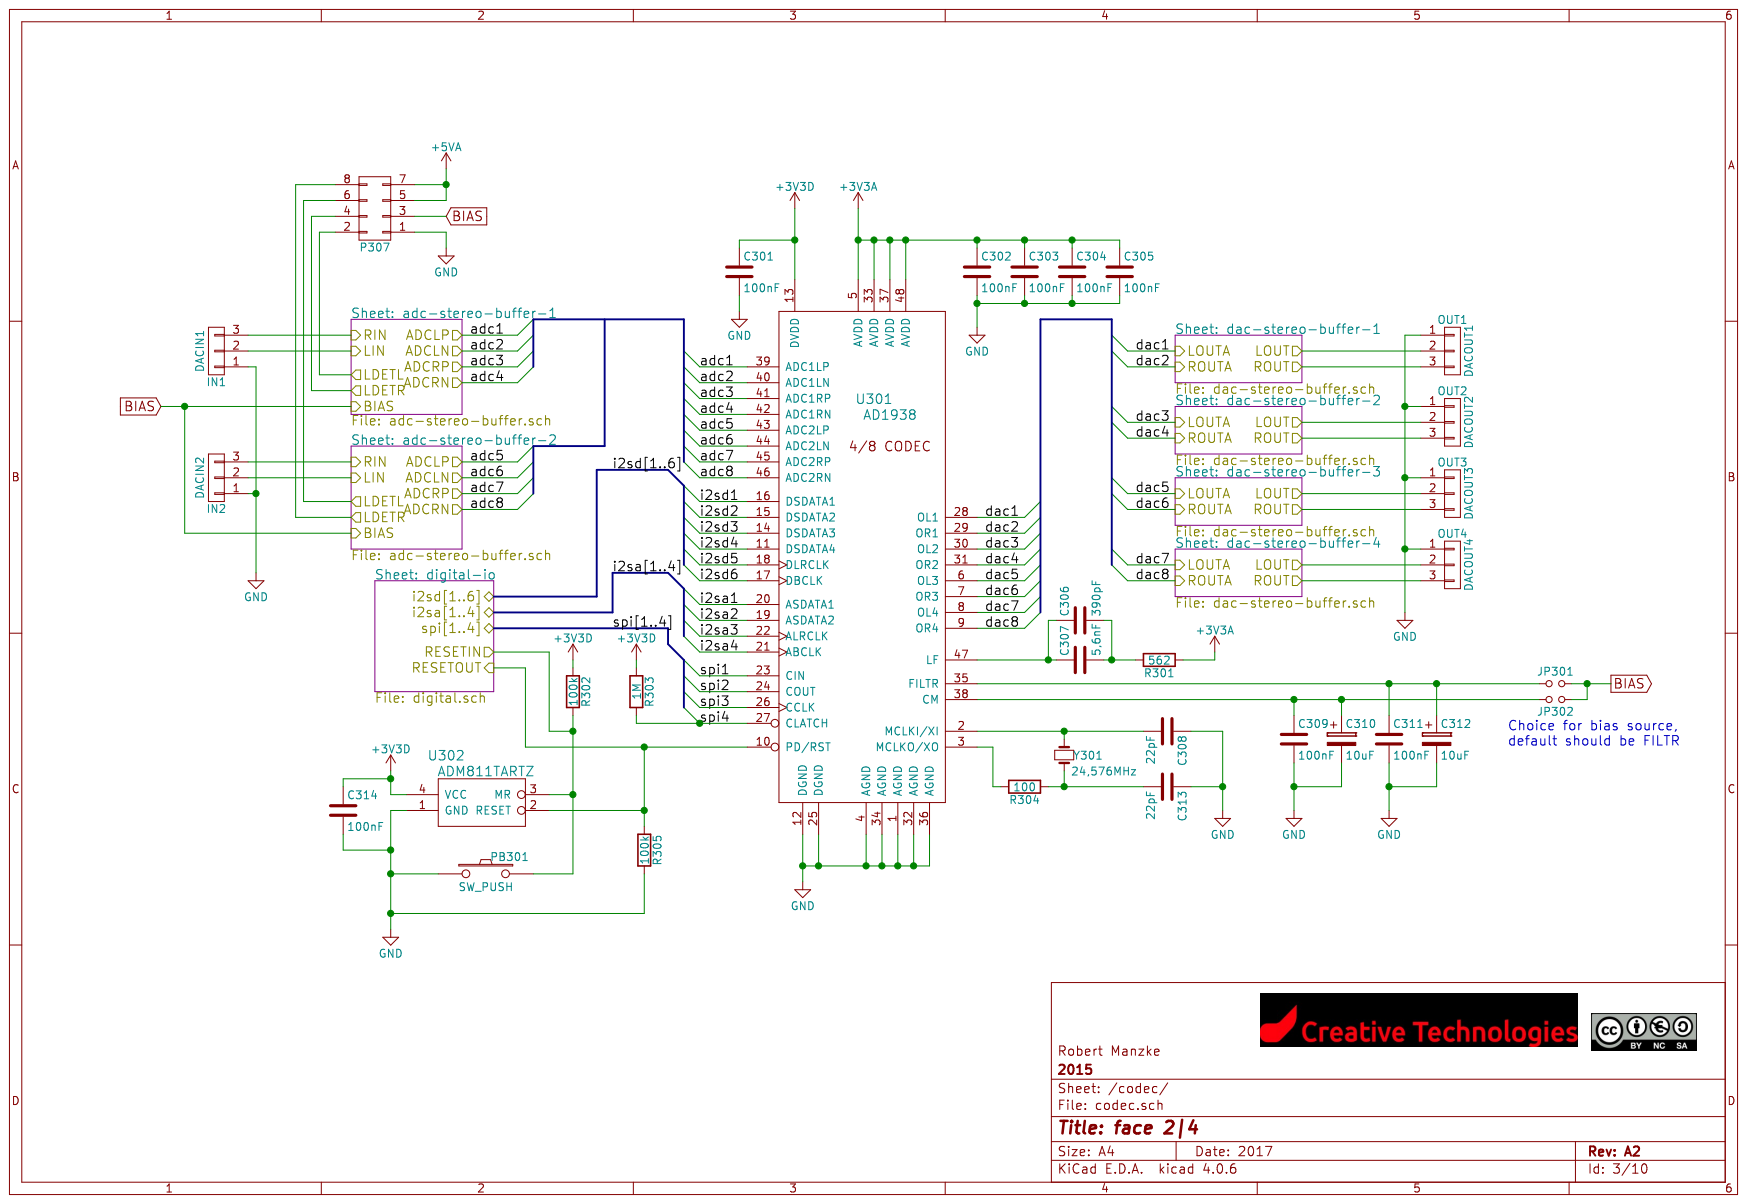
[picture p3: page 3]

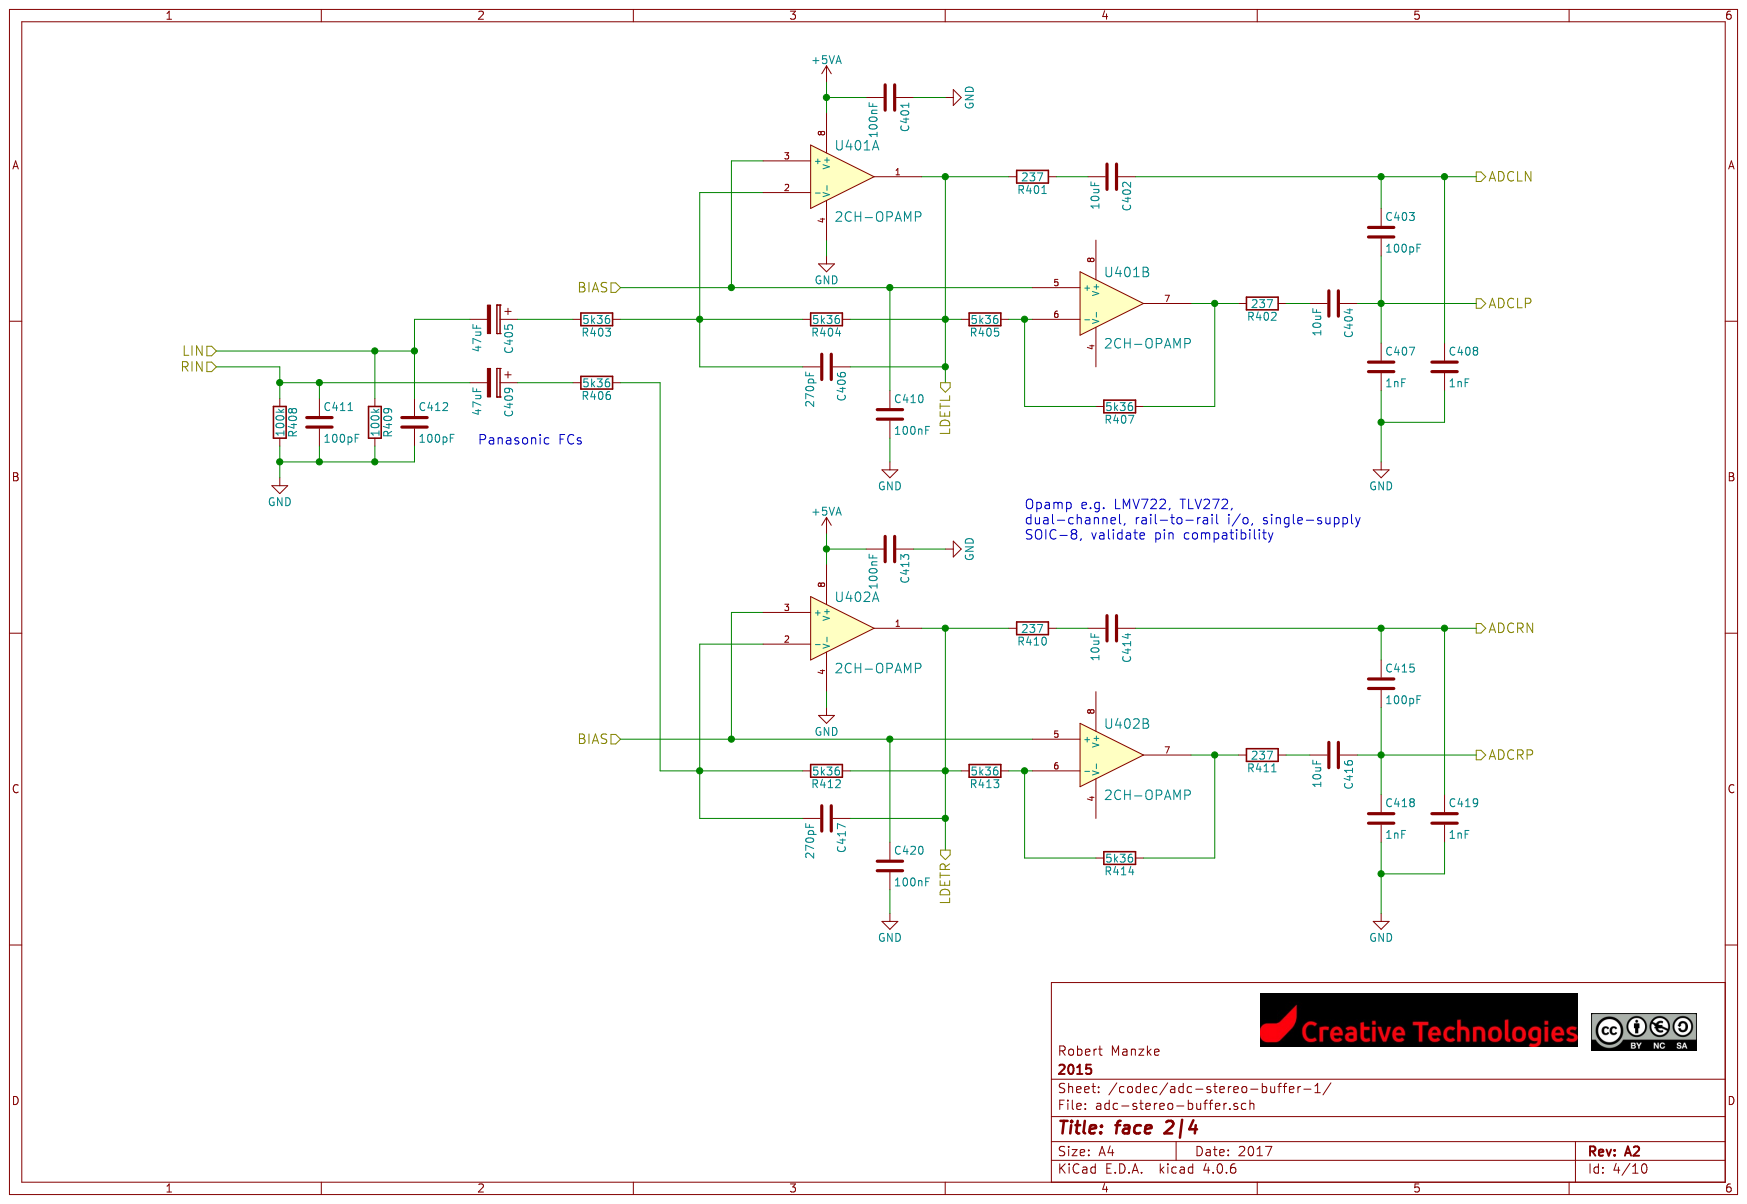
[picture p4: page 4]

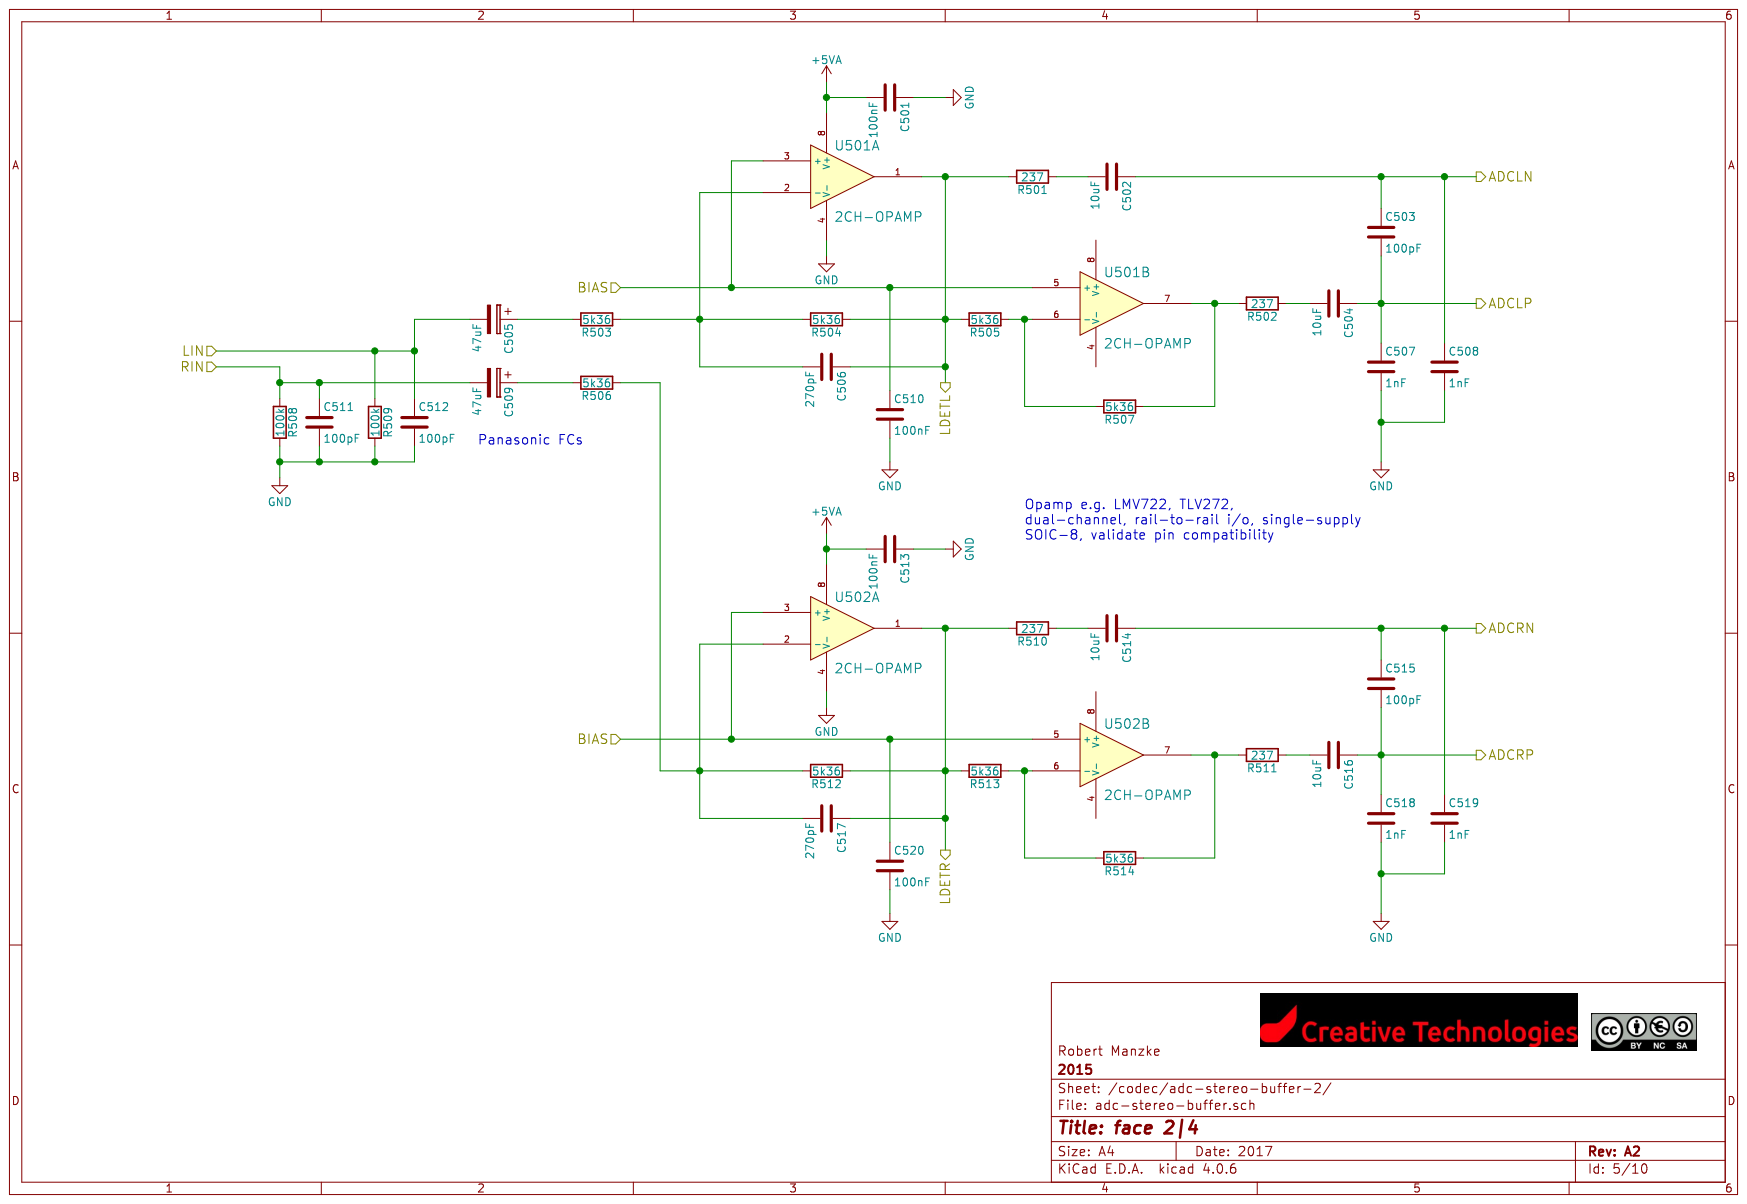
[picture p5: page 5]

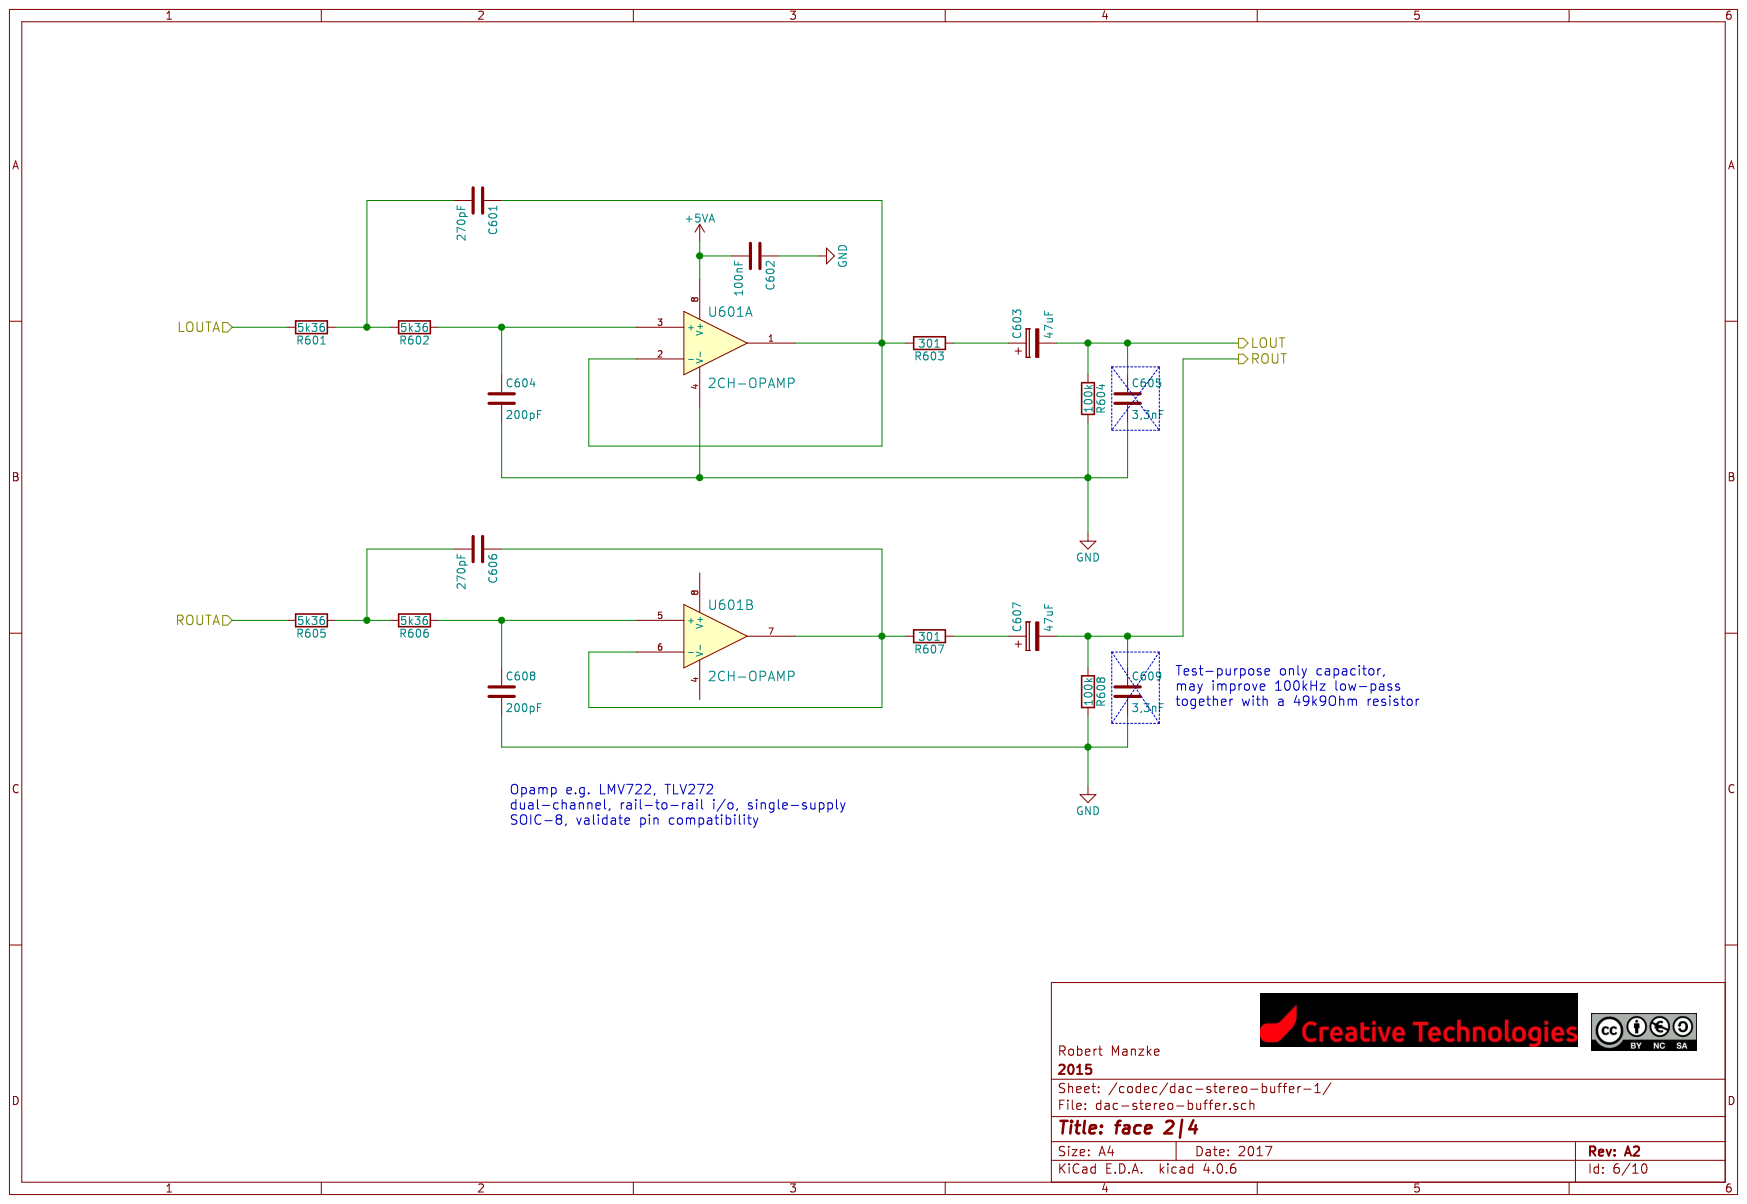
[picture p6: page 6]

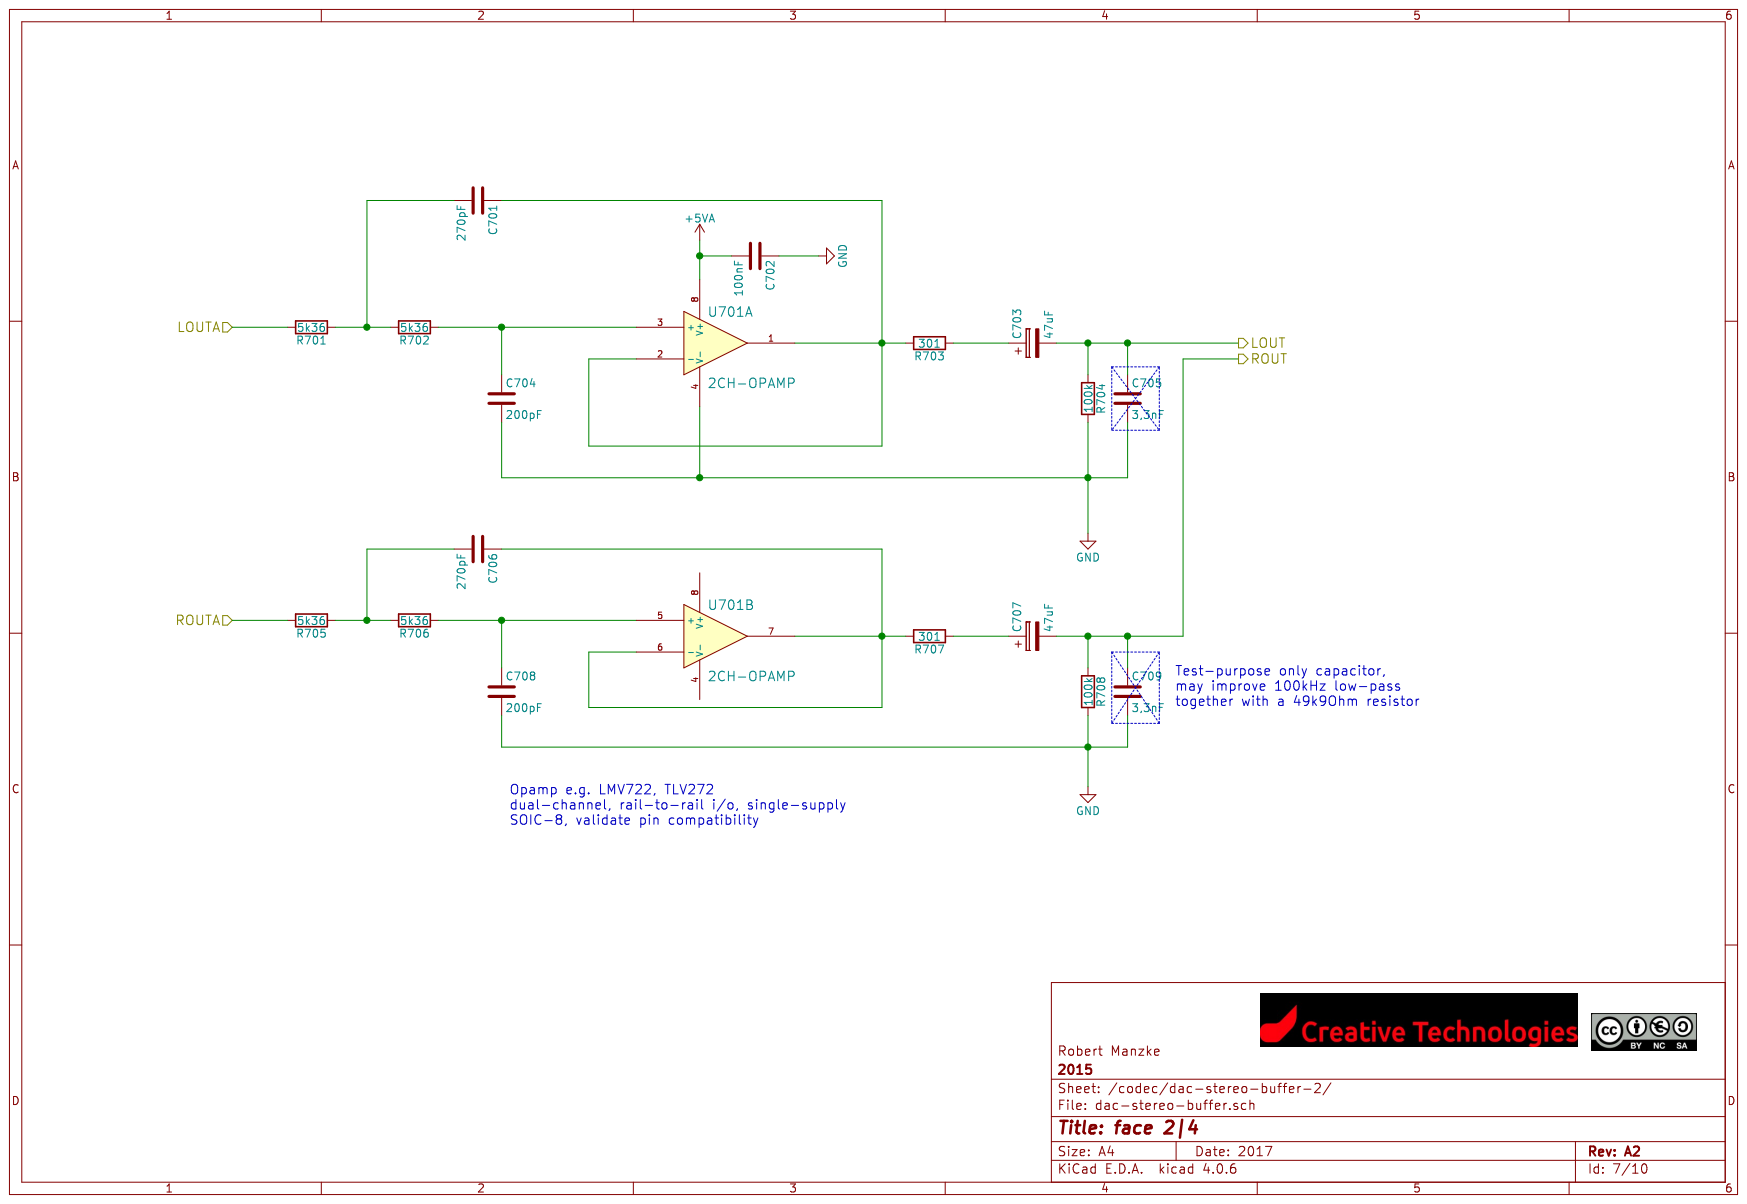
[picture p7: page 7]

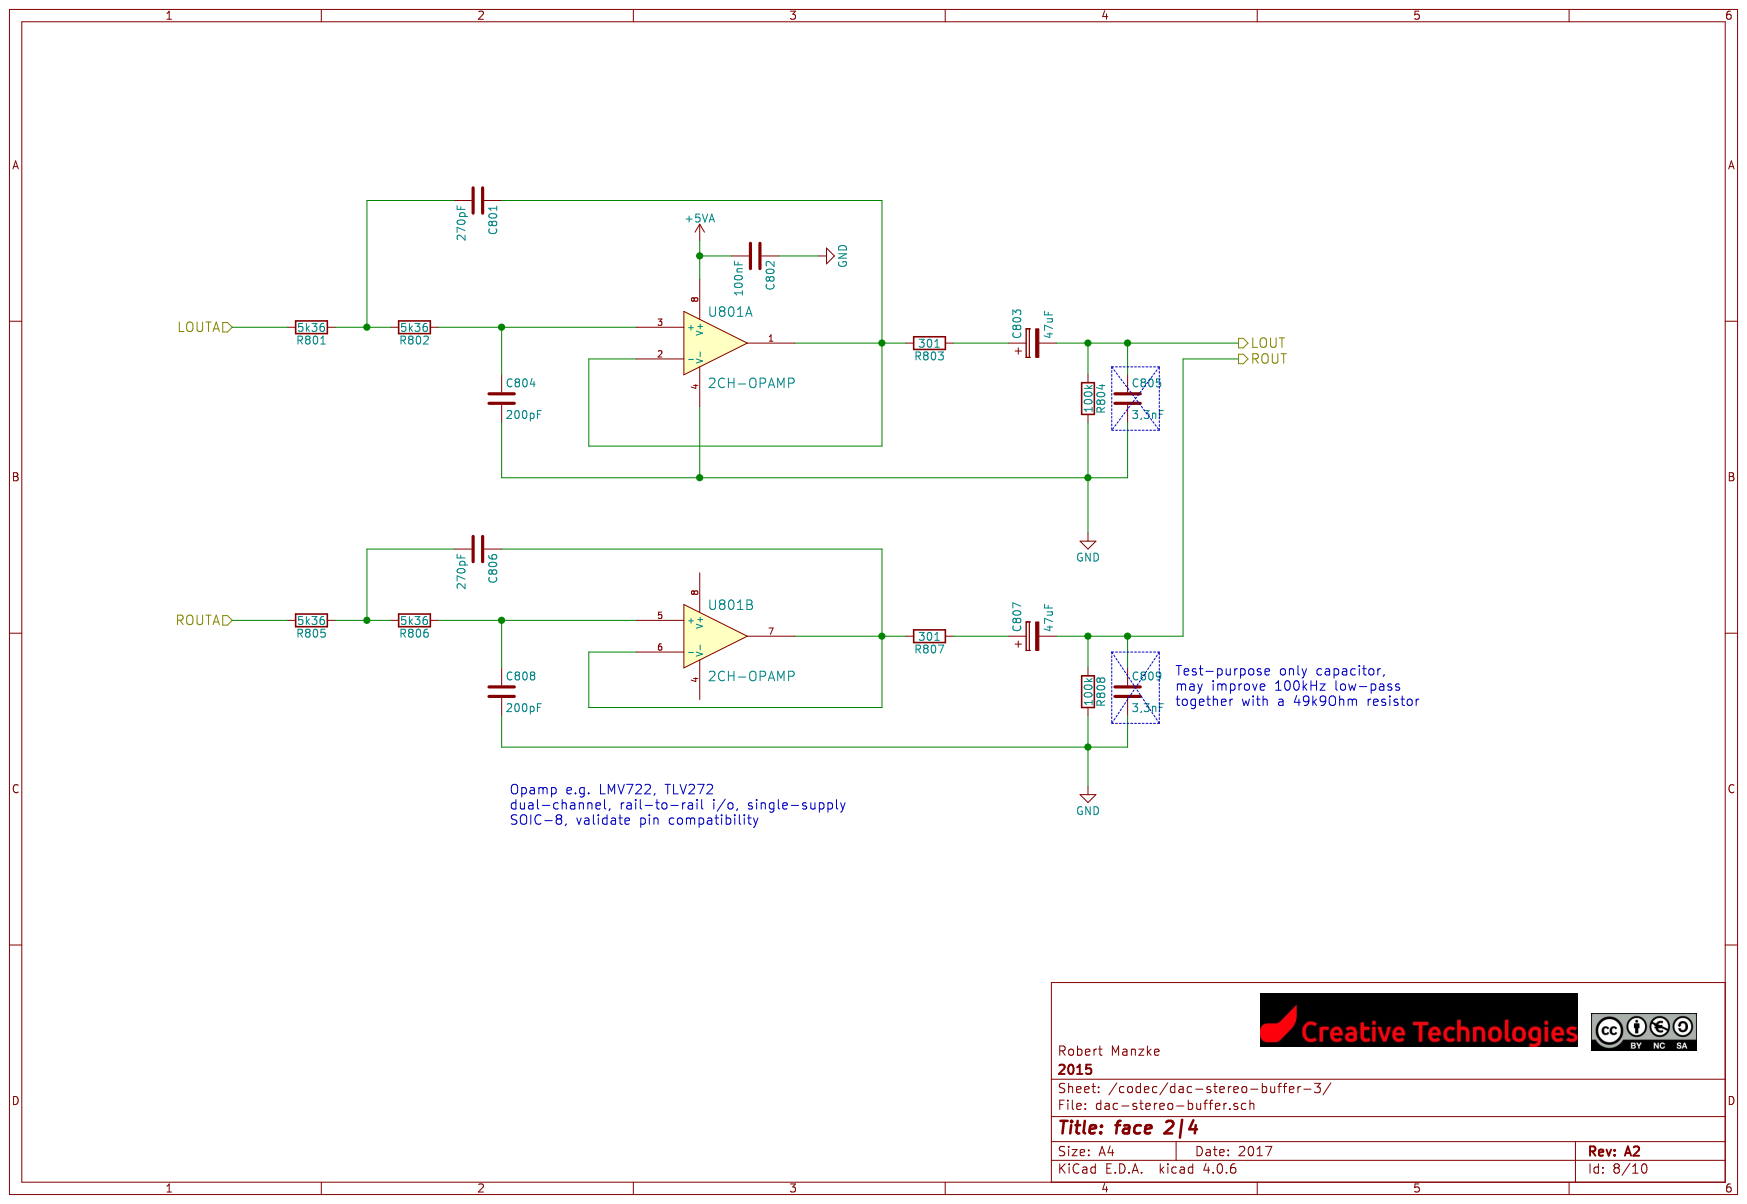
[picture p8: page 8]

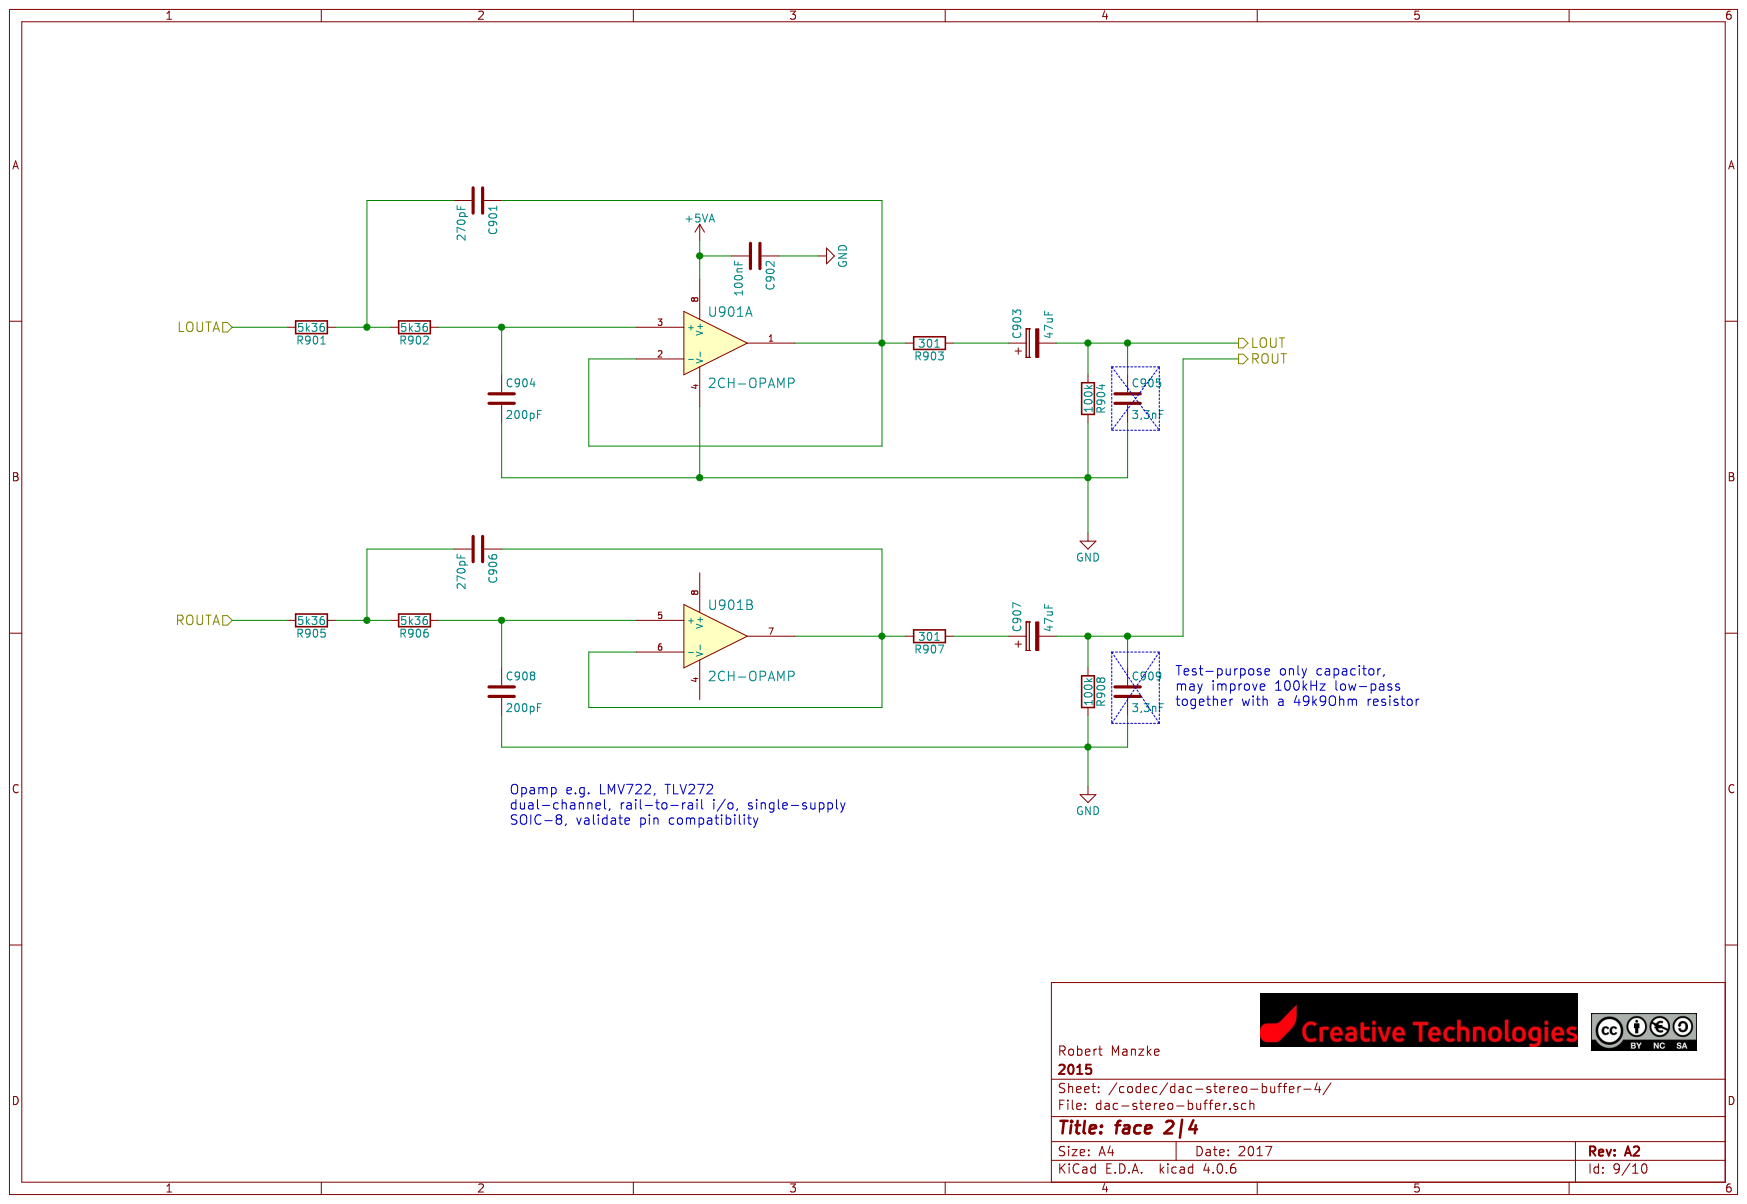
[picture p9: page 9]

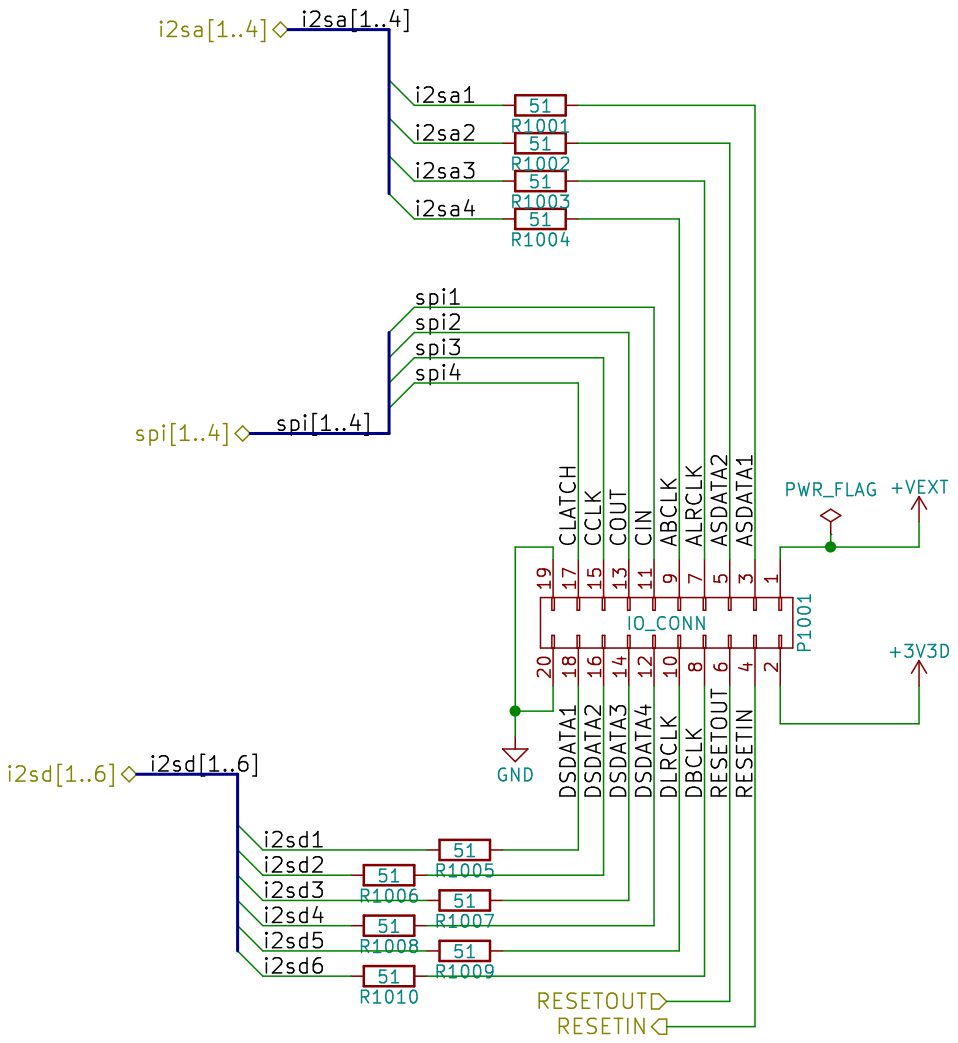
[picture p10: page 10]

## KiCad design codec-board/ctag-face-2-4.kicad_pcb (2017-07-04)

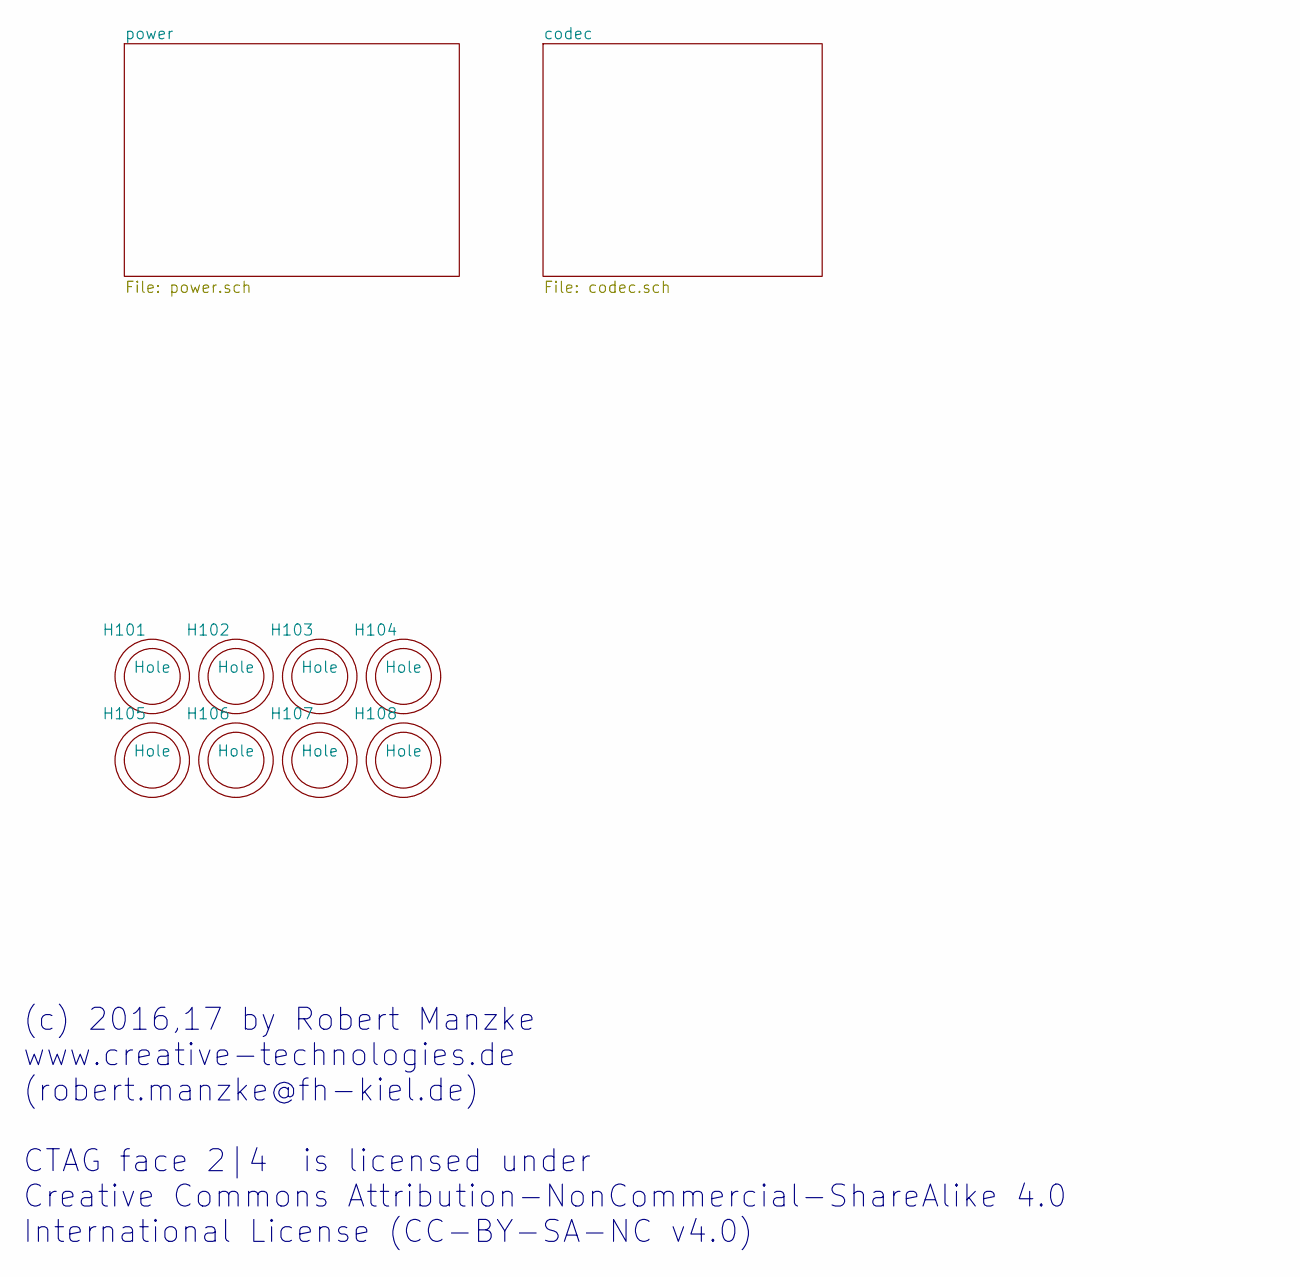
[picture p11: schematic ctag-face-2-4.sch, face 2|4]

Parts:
H101, H102, H103, H104, H105, H106, H107, H108: Hole; Hole_3mm

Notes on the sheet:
(c) 2016,17 by Robert Manzke www.creative-technologies.de (robert.manzke@fh-kiel.de) CTAG face 2|4 is licensed under Creative Commons Attribution-NonCommercial-ShareAlike 4.0 International License (CC-BY-SA-NC v4.0)

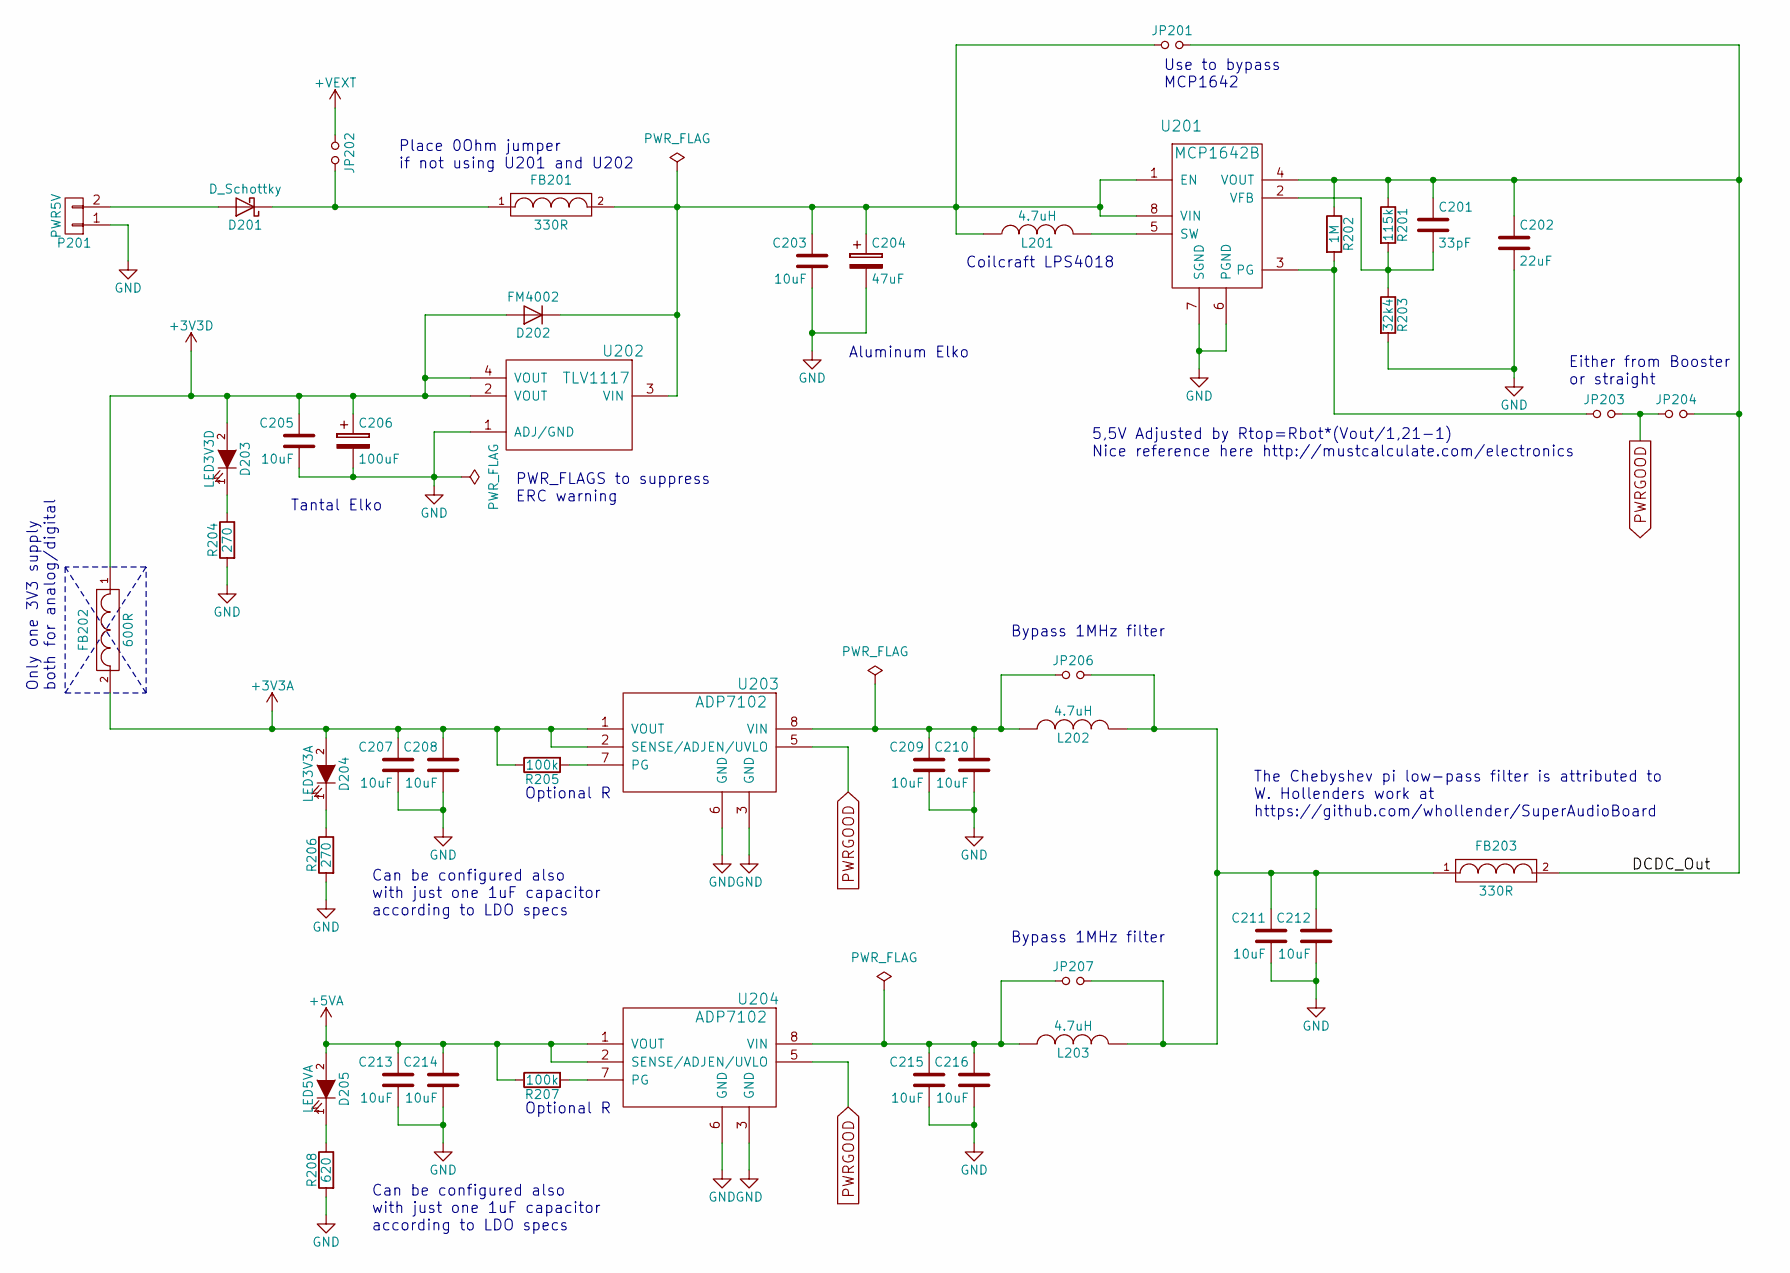
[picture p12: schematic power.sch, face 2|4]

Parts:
C201: 33pF; C_0603_HandSoldering
C202: 22uF; C_1210_HandSoldering
C203, C205, C207, C208, C209, C210, C211, C212, C213, C214, C215, C216: 10uF; C_1210_HandSoldering
C204: 47uF; c_elec_6.3x5.7
C206: 100uF; TantalC_SizeB_EIA-3528_HandSoldering
D201: D_Schottky; SOD-123
D202: FM4002; Diode-Universal-SMA-SMB_Handsoldering
D203: LED3V3D; LED-1206
D204: LED3V3A; LED-1206
D205: LED5VA; LED-1206
FB201, FB203: 330R; R_0805_HandSoldering
FB202: 600R; R_0805_HandSoldering
JP201, JP206, JP207: Jumper_NO_Small; R_0805_HandSoldering
JP202: Jumper_NO_Small; Pin_Header_Straight_1x02
JP203, JP204: Jumper_NO_Small; R_0603_HandSoldering
L201, L202, L203: 4.7uH; LPS4018
P201: PWR5V; Pin_Header_Straight_1x02
R201: 115k; R_0603_HandSoldering
R202: 1M; R_0603_HandSoldering
R203: 32k4; R_0603_HandSoldering
R204, R206: 270; R_0603_HandSoldering
R205, R207: 100k; R_0603_HandSoldering
R208: 620; R_0603_HandSoldering
U201: MCP1642B; MSOP-8_3x3mm_Pitch0.65mm
U202: TLV1117; SOT-223
U203, U204: ADP7102; SOIC-8_3.9x4.9mm_Pitch1.27mm

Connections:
+3V3A: C207.1, C208.1, D204.2 (A), FB202.2, R205.1, U203.1 (VOUT), U203.2 (SENSE/ADJ); also elsewhere on the board
+3V3D: C205.1, C206.1, D202.2 (A), D203.2 (A), FB202.1, U202.2 (VOUT), U202.4 (VOUT); also elsewhere on the board
+5VA: C213.1, C214.1, D205.2 (A), R207.1, U204.1 (VOUT), U204.2 (SENSE/ADJ); also elsewhere on the board
+VEXT: JP202.1; also elsewhere on the board
/power/DCDC_Out: C201.1, C202.1, FB203.2, JP201.2, JP204.2, R201.1, R202.1, U201.4 (VOUT)
GND: C202.2, C203.2, C204.2, C205.2, C206.2, C207.2, C208.2, C209.2, C210.2, C211.2, C212.2, C213.2, C214.2, C215.2, C216.2, P201.1, R203.2, R204.2, R206.2, R208.2, U201.6 (PGND), U201.7 (SGND), U202.1 (ADJ/GND), U203.3 (GND), U203.6 (GND), U204.3 (GND), U204.6 (GND); also elsewhere on the board
unnamed: C201.2, R201.2, R203.1, U201.2 (VFB)
unnamed: C203.1, C204.1, D202.1 (K), FB201.2, JP201.1, L201.1, U201.1 (EN), U201.8 (VIN), U202.3 (VIN)
unnamed: C209.1, C210.1, JP206.1, L202.2, U203.8 (VIN)
unnamed: C211.1, C212.1, FB203.1, JP206.2, JP207.2, L202.1, L203.1
unnamed: C215.1, C216.1, JP207.1, L203.2, U204.8 (VIN)
unnamed: D201.1 (K), FB201.1, JP202.2
unnamed: D201.2 (A), P201.2
unnamed: D203.1 (K), R204.1
unnamed: D204.1 (K), R206.1
unnamed: D205.1 (K), R208.1
unnamed: JP203.1, R202.2, U201.3 (PG)
unnamed: L201.2, U201.5 (SW)
unnamed: R205.2, U203.7 (PG)
unnamed: R207.2, U204.7 (PG)
PWRGOOD: JP203.2, JP204.1, U203.5 (EN/UVLO), U204.5 (EN/UVLO)

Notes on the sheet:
5,5V Adjusted by Rtop=Rbot*(Vout/1,21-1) Nice reference here http://mustcalculate.com/electronics
Tantal Elko
Aluminum Elko
PWR_FLAGS to suppress ERC warning
Use to bypass MCP1642
Bypass 1MHz filter
Only one 3V3 supply both for analog/digital
Optional R
Either from Booster or straight
Coilcraft LPS4018
Place 0Ohm jumper if not using U201 and U202
The Chebyshev pi low-pass filter is attributed to W. Hollenders work at https://github.com/whollender/SuperAudioBoard
Can be configured also with just one 1uF capacitor according to LDO specs

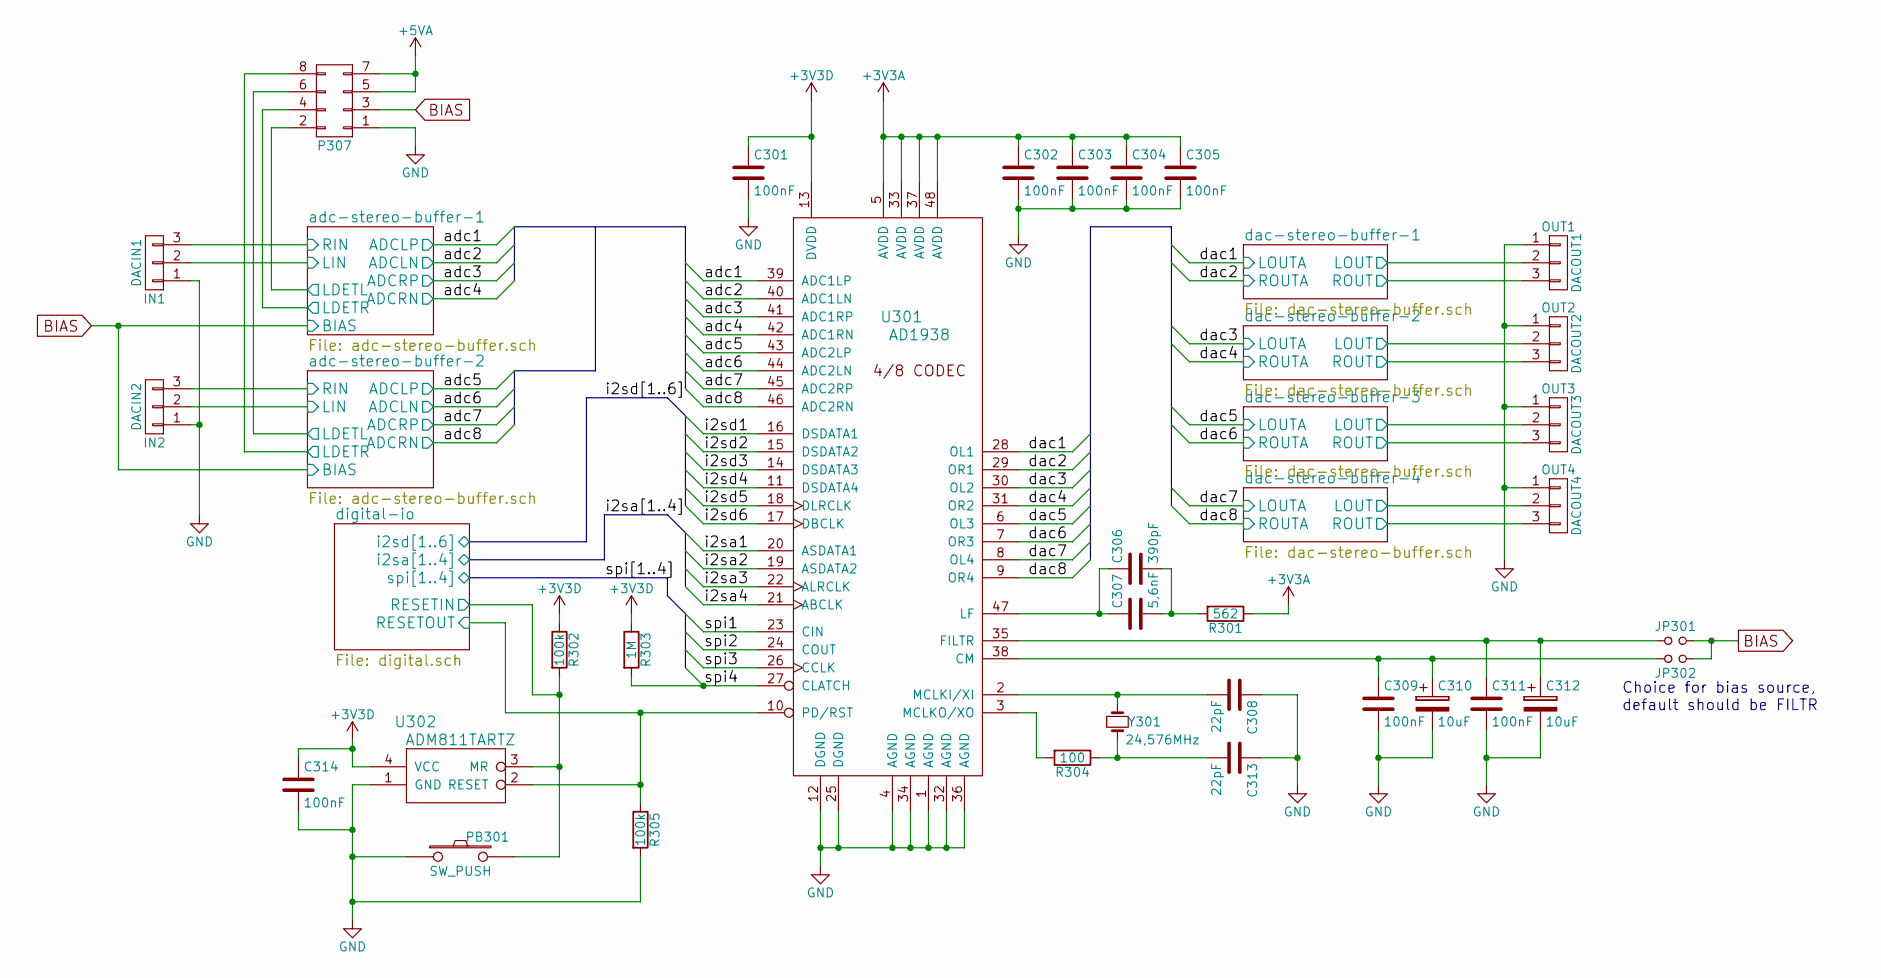
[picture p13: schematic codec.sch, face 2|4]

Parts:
C301, C302, C303, C304, C305, C309, C311, C314: 100nF; C_0603_HandSoldering
C306: 390pF; C_0603_HandSoldering
C307: 5,6nF; C_0603_HandSoldering
C308, C313: 22pF; C_0603_HandSoldering
C310, C312: 10uF; c_elec_4x5.7
IN1: DACIN1; Pin_Header_Straight_1x03
IN2: DACIN2; Pin_Header_Straight_1x03
JP301, JP302: Jumper_NO_Small; R_0603_HandSoldering
OUT1: DACOUT1; Pin_Header_Straight_1x03
OUT2: DACOUT2; Pin_Header_Straight_1x03
OUT3: DACOUT3; Pin_Header_Straight_1x03
OUT4: DACOUT4; Pin_Header_Straight_1x03
P307: Pin_Header_Straight_2x04
PB301: SW_PUSH; SW_SPST_PTS645
R301: 562; R_0603_HandSoldering
R302, R305: 100k; R_0603_HandSoldering
R303: 1M; R_0603_HandSoldering
R304: 100; R_0603_HandSoldering
U301: AD1938; LQFP-48_7x7mm_Pitch0.5mm
U302: ADM811TARTZ; SOT-143
Y301: 24,576MHz; Q_49U3HMS

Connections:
+3V3A: C302.1, C303.1, C304.1, C305.1, R301.1, U301.5 (AVDD), U301.33 (AVDD), U301.37 (AVDD), U301.48 (AVDD); also elsewhere on the board
+3V3D: C301.1, C314.1, R302.1, R303.1, U301.13 (DVDD), U302.4 (VCC); also elsewhere on the board
+5VA: P307.5, P307.7; also elsewhere on the board
/codec/adc1: U301.39 (ADC1LP); also elsewhere on the board
/codec/adc2: U301.40 (ADC1LN); also elsewhere on the board
/codec/adc3: U301.41 (ADC1RP); also elsewhere on the board
/codec/adc4: U301.42 (ADC1RN); also elsewhere on the board
/codec/adc5: U301.43 (ADC2LP); also elsewhere on the board
/codec/adc6: U301.44 (ADC2LN); also elsewhere on the board
/codec/adc7: U301.45 (ADC2RP); also elsewhere on the board
/codec/adc8: U301.46 (ADC2RN); also elsewhere on the board
/codec/adc-stereo-buffer-1/LDETL: P307.2; also elsewhere on the board
/codec/adc-stereo-buffer-1/LDETR: P307.4; also elsewhere on the board
/codec/adc-stereo-buffer-1/LIN: IN1.2; also elsewhere on the board
/codec/adc-stereo-buffer-1/RIN: IN1.3; also elsewhere on the board
/codec/adc-stereo-buffer-2/LDETL: P307.6; also elsewhere on the board
/codec/adc-stereo-buffer-2/LDETR: P307.8; also elsewhere on the board
/codec/adc-stereo-buffer-2/LIN: IN2.2; also elsewhere on the board
/codec/adc-stereo-buffer-2/RIN: IN2.3; also elsewhere on the board
/codec/dac1: U301.28 (OL1); also elsewhere on the board
/codec/dac2: U301.29 (OR1); also elsewhere on the board
/codec/dac3: U301.30 (OL2); also elsewhere on the board
/codec/dac4: U301.31 (OR2); also elsewhere on the board
/codec/dac5: U301.6 (OL3); also elsewhere on the board
/codec/dac6: U301.7 (OR3); also elsewhere on the board
/codec/dac7: U301.8 (OL4); also elsewhere on the board
/codec/dac8: U301.9 (OR4); also elsewhere on the board
/codec/dac-stereo-buffer-1/LOUT: OUT1.2; also elsewhere on the board
/codec/dac-stereo-buffer-1/ROUT: OUT1.3; also elsewhere on the board
/codec/dac-stereo-buffer-2/LOUT: OUT2.2; also elsewhere on the board
/codec/dac-stereo-buffer-2/ROUT: OUT2.3; also elsewhere on the board
/codec/dac-stereo-buffer-3/LOUT: OUT3.2; also elsewhere on the board
/codec/dac-stereo-buffer-3/ROUT: OUT3.3; also elsewhere on the board
/codec/dac-stereo-buffer-4/LOUT: OUT4.2; also elsewhere on the board
/codec/dac-stereo-buffer-4/ROUT: OUT4.3; also elsewhere on the board
/codec/digital-io/RESETIN: PB301.2, R302.2, U302.3 (MR); also elsewhere on the board
/codec/digital-io/RESETOUT: R305.1, U301.10 (PD/RST), U302.2 (RESET); also elsewhere on the board
/codec/i2sa1: U301.20 (ASDATA1); also elsewhere on the board
/codec/i2sa2: U301.19 (ASDATA2); also elsewhere on the board
/codec/i2sa3: U301.22 (ALRCLK); also elsewhere on the board
/codec/i2sa4: U301.21 (ABCLK); also elsewhere on the board
/codec/i2sd1: U301.16 (DSDATA1); also elsewhere on the board
/codec/i2sd2: U301.15 (DSDATA2); also elsewhere on the board
/codec/i2sd3: U301.14 (DSDATA3); also elsewhere on the board
/codec/i2sd4: U301.11 (DSDATA4); also elsewhere on the board
/codec/i2sd5: U301.18 (DLRCLK); also elsewhere on the board
/codec/i2sd6: U301.17 (DBCLK); also elsewhere on the board
/codec/spi1: U301.23 (CIN); also elsewhere on the board
/codec/spi2: U301.24 (COUT); also elsewhere on the board
/codec/spi3: U301.26 (CCLK); also elsewhere on the board
/codec/spi4: R303.2, U301.27 (CLATCH); also elsewhere on the board
BIAS: JP301.2, JP302.1, P307.3; also elsewhere on the board
GND: C301.2, C302.2, C303.2, C304.2, C305.2, C308.1, C309.2, C310.2, C311.2, C312.2, C313.1, C314.2, IN1.1, IN2.1, OUT1.1, OUT2.1, OUT3.1, OUT4.1, P307.1, PB301.1, R305.2, U301.1 (AGND), U301.4 (AGND), U301.12 (DGND), U301.25 (DGND), U301.32 (AGND), U301.34 (AGND), U301.36 (AGND), U302.1 (GND); also elsewhere on the board
unnamed: C306.1, C307.1, U301.47 (LF)
unnamed: C306.2, C307.2, R301.2
unnamed: C308.2, U301.2 (MCLKI/XI), Y301.1
unnamed: C309.1, C310.1, JP302.2, U301.38 (CM)
unnamed: C311.1, C312.1, JP301.1, U301.35 (FILTR)
unnamed: C313.2, R304.1, Y301.2
unnamed: R304.2, U301.3 (MCLKO/XO)

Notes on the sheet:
Choice for bias source, default should be FILTR

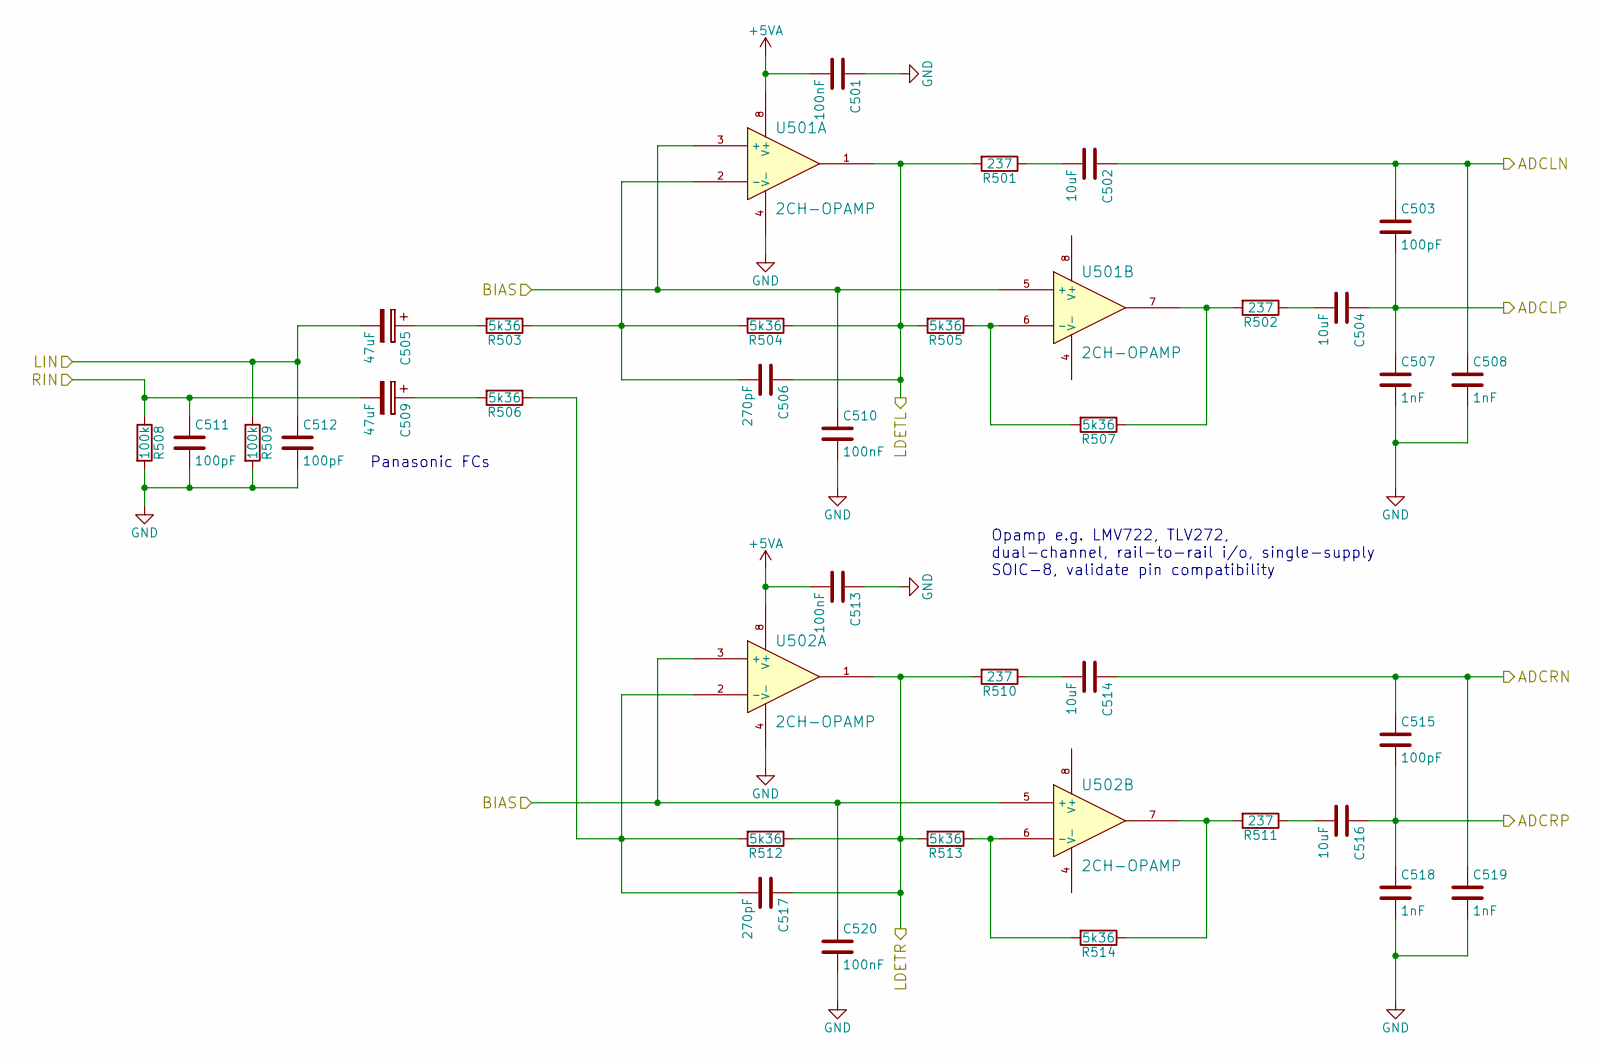
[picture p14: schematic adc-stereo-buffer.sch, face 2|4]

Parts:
C401, C410, C413, C420: 100nF; C_0603_HandSoldering
C402, C404, C414, C416: 10uF; C_0805_HandSoldering
C403, C411, C412, C415: 100pF; C_0603_HandSoldering
C405, C409: 47uF; c_elec_6.3x5.7
C406, C417: 270pF; C_0603_HandSoldering
C407, C408, C418, C419: 1nF; C_0603_HandSoldering
R401, R402, R410, R411: 237; R_0603_HandSoldering
R403, R404, R405, R406, R407, R412, R413, R414: 5k36; R_0603_HandSoldering
R408, R409: 100k; R_0603_HandSoldering
U401, U402: 2CH-OPAMP; SOIC-8_3.9x4.9mm_Pitch1.27mm

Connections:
+5VA: C401.2, C413.2, U401.8 (V+), U402.8 (V+); also elsewhere on the board
/codec/adc1: C403.2, C404.1, C407.1; also elsewhere on the board
/codec/adc2: C402.1, C403.1, C408.1; also elsewhere on the board
/codec/adc3: C415.2, C416.1, C418.1; also elsewhere on the board
/codec/adc4: C414.1, C415.1, C419.1; also elsewhere on the board
/codec/adc-stereo-buffer-1/LDETL: C406.1, R401.2, R404.1, R405.2, U401.1; also elsewhere on the board
/codec/adc-stereo-buffer-1/LDETR: C417.1, R410.2, R412.1, R413.2, U402.1; also elsewhere on the board
/codec/adc-stereo-buffer-1/LIN: C405.2, C412.1, R409.1; also elsewhere on the board
/codec/adc-stereo-buffer-1/RIN: C409.2, C411.1, R408.1; also elsewhere on the board
BIAS: C410.1, C420.1, U401.3 (+), U401.5 (+), U402.3 (+), U402.5 (+); also elsewhere on the board
GND: C401.1, C407.2, C408.2, C410.2, C411.2, C412.2, C413.1, C418.2, C419.2, C420.2, R408.2, R409.2, U401.4 (V-), U402.4 (V-); also elsewhere on the board
unnamed: C402.2, R401.1
unnamed: C404.2, R402.1
unnamed: C405.1, R403.2
unnamed: C406.2, R403.1, R404.2, U401.2 (-)
unnamed: C409.1, R406.2
unnamed: C414.2, R410.1
unnamed: C416.2, R411.1
unnamed: C417.2, R406.1, R412.2, U402.2 (-)
unnamed: R402.2, R407.1, U401.7
unnamed: R405.1, R407.2, U401.6 (-)
unnamed: R411.2, R414.1, U402.7
unnamed: R413.1, R414.2, U402.6 (-)

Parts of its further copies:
C501, C510, C513, C520: 100nF; C_0603_HandSoldering
C502, C504, C514, C516: 10uF; C_0805_HandSoldering
C503, C511, C512, C515: 100pF; C_0603_HandSoldering
C505, C509: 47uF; c_elec_6.3x5.7
C506, C517: 270pF; C_0603_HandSoldering
C507, C508, C518, C519: 1nF; C_0603_HandSoldering
R501, R502, R510, R511: 237; R_0603_HandSoldering
R503, R504, R505, R506, R507, R512, R513, R514: 5k36; R_0603_HandSoldering
R508, R509: 100k; R_0603_HandSoldering
U501, U502: 2CH-OPAMP; SOIC-8_3.9x4.9mm_Pitch1.27mm

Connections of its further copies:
+5VA: C501.2, C513.2, U501.8 (V+), U502.8 (V+); also elsewhere on the board
/codec/adc5: C503.2, C504.1, C507.1; also elsewhere on the board
/codec/adc6: C502.1, C503.1, C508.1; also elsewhere on the board
/codec/adc7: C515.2, C516.1, C518.1; also elsewhere on the board
/codec/adc8: C514.1, C515.1, C519.1; also elsewhere on the board
/codec/adc-stereo-buffer-2/LDETL: C506.1, R501.2, R504.1, R505.2, U501.1; also elsewhere on the board
/codec/adc-stereo-buffer-2/LDETR: C517.1, R510.2, R512.1, R513.2, U502.1; also elsewhere on the board
/codec/adc-stereo-buffer-2/LIN: C505.2, C512.1, R509.1; also elsewhere on the board
/codec/adc-stereo-buffer-2/RIN: C509.2, C511.1, R508.1; also elsewhere on the board
BIAS: C510.1, C520.1, U501.3 (+), U501.5 (+), U502.3 (+), U502.5 (+); also elsewhere on the board
GND: C501.1, C507.2, C508.2, C510.2, C511.2, C512.2, C513.1, C518.2, C519.2, C520.2, R508.2, R509.2, U501.4 (V-), U502.4 (V-); also elsewhere on the board
unnamed: C502.2, R501.1
unnamed: C504.2, R502.1
unnamed: C505.1, R503.2
unnamed: C506.2, R503.1, R504.2, U501.2 (-)
unnamed: C509.1, R506.2
unnamed: C514.2, R510.1
unnamed: C516.2, R511.1
unnamed: C517.2, R506.1, R512.2, U502.2 (-)
unnamed: R502.2, R507.1, U501.7
unnamed: R505.1, R507.2, U501.6 (-)
unnamed: R511.2, R514.1, U502.7
unnamed: R513.1, R514.2, U502.6 (-)

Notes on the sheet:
Opamp e.g. LMV722, TLV272, dual-channel, rail-to-rail i/o, single-supply SOIC-8, validate pin compatibility
Panasonic FCs

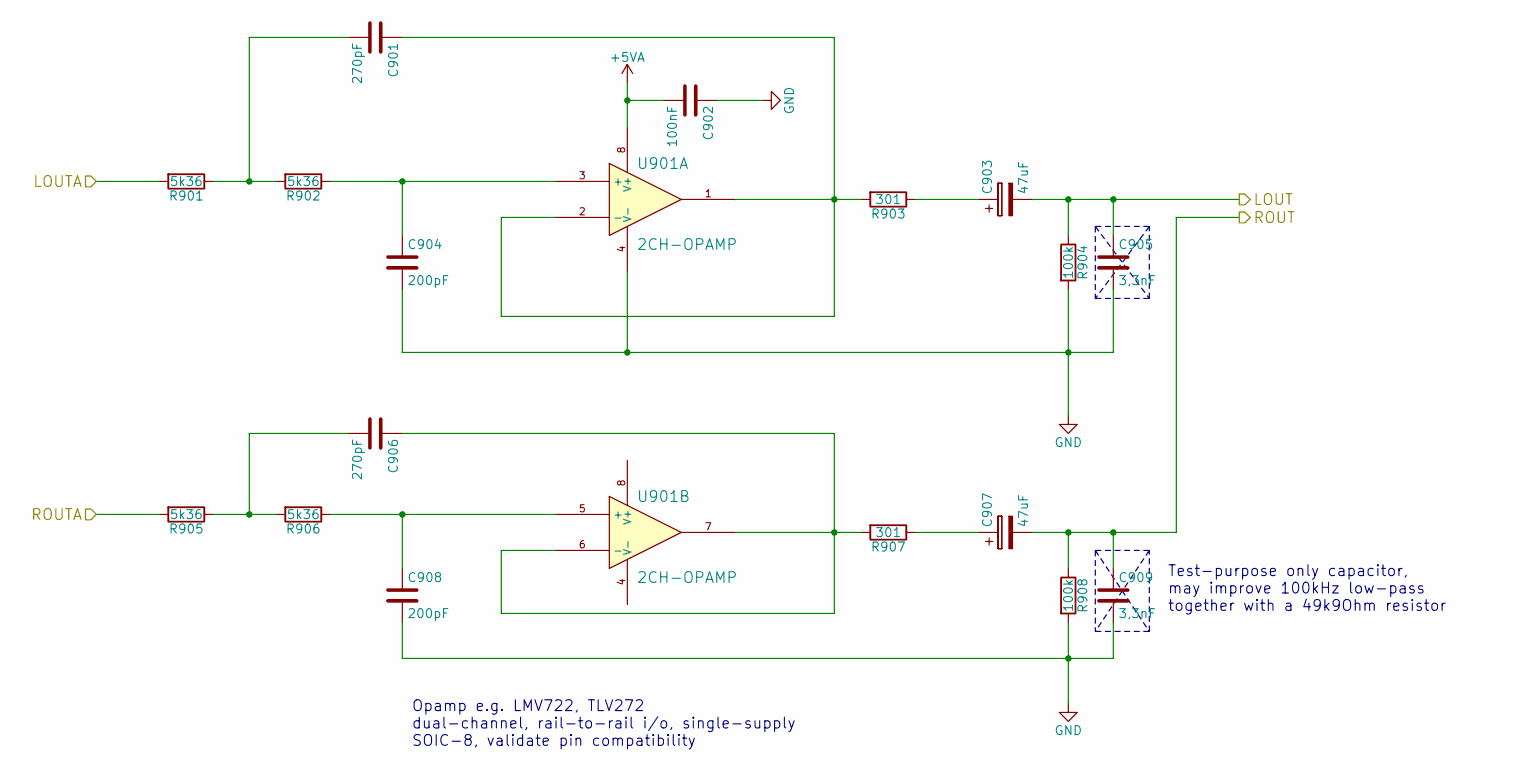
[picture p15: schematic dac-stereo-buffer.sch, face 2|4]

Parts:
C601, C606: 270pF; C_0603_HandSoldering
C602: 100nF; C_0603_HandSoldering
C603, C607: 47uF; c_elec_6.3x5.7
C604, C608: 200pF; C_0603_HandSoldering
C605, C609: 3,3nF; C_0603_HandSoldering
R601, R602, R605, R606: 5k36; R_0603_HandSoldering
R603, R607: 301; R_0603_HandSoldering
R604, R608: 100k; R_0603_HandSoldering
U601: 2CH-OPAMP; SOIC-8_3.9x4.9mm_Pitch1.27mm

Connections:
+5VA: C602.2, U601.8 (V+); also elsewhere on the board
/codec/dac1: R601.2; also elsewhere on the board
/codec/dac2: R605.2; also elsewhere on the board
/codec/dac-stereo-buffer-1/LOUT: C603.2, C605.1, R604.1; also elsewhere on the board
/codec/dac-stereo-buffer-1/ROUT: C607.2, C609.1, R608.1; also elsewhere on the board
GND: C602.1, C604.2, C605.2, C608.2, C609.2, R604.2, R608.2, U601.4 (V-); also elsewhere on the board
unnamed: C601.1, R603.2, U601.1, U601.2 (-)
unnamed: C601.2, R601.1, R602.2
unnamed: C603.1, R603.1
unnamed: C604.1, R602.1, U601.3 (+)
unnamed: C606.1, R607.2, U601.6 (-), U601.7
unnamed: C606.2, R605.1, R606.2
unnamed: C607.1, R607.1
unnamed: C608.1, R606.1, U601.5 (+)

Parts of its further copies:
C701, C706, C801, C806, C901, C906: 270pF; C_0603_HandSoldering
C702, C802, C902: 100nF; C_0603_HandSoldering
C703, C707, C803, C807, C903, C907: 47uF; c_elec_6.3x5.7
C704, C708, C804, C808, C904, C908: 200pF; C_0603_HandSoldering
C705, C709, C805, C809, C905, C909: 3,3nF; C_0603_HandSoldering
R701, R702, R705, R706, R801, R802, R805, R806, R901, R902, R905, R906: 5k36; R_0603_HandSoldering
R703, R707, R803, R807, R903, R907: 301; R_0603_HandSoldering
R704, R708, R804, R808, R904, R908: 100k; R_0603_HandSoldering
U701, U801, U901: 2CH-OPAMP; SOIC-8_3.9x4.9mm_Pitch1.27mm

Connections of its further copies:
+5VA: C702.2, C802.2, C902.2, U701.8 (V+), U801.8 (V+), U901.8 (V+); also elsewhere on the board
/codec/dac3: R701.2; also elsewhere on the board
/codec/dac4: R705.2; also elsewhere on the board
/codec/dac5: R801.2; also elsewhere on the board
/codec/dac6: R805.2; also elsewhere on the board
/codec/dac7: R901.2; also elsewhere on the board
/codec/dac8: R905.2; also elsewhere on the board
/codec/dac-stereo-buffer-2/LOUT: C703.2, C705.1, R704.1; also elsewhere on the board
/codec/dac-stereo-buffer-2/ROUT: C707.2, C709.1, R708.1; also elsewhere on the board
/codec/dac-stereo-buffer-3/LOUT: C803.2, C805.1, R804.1; also elsewhere on the board
/codec/dac-stereo-buffer-3/ROUT: C807.2, C809.1, R808.1; also elsewhere on the board
/codec/dac-stereo-buffer-4/LOUT: C903.2, C905.1, R904.1; also elsewhere on the board
/codec/dac-stereo-buffer-4/ROUT: C907.2, C909.1, R908.1; also elsewhere on the board
GND: C702.1, C704.2, C705.2, C708.2, C709.2, C802.1, C804.2, C805.2, C808.2, C809.2, C902.1, C904.2, C905.2, C908.2, C909.2, R704.2, R708.2, R804.2, R808.2, R904.2, R908.2, U701.4 (V-), U801.4 (V-), U901.4 (V-); also elsewhere on the board
unnamed: C701.1, R703.2, U701.1, U701.2 (-)
unnamed: C701.2, R701.1, R702.2
unnamed: C703.1, R703.1
unnamed: C704.1, R702.1, U701.3 (+)
unnamed: C706.1, R707.2, U701.6 (-), U701.7
unnamed: C706.2, R705.1, R706.2
unnamed: C707.1, R707.1
unnamed: C708.1, R706.1, U701.5 (+)
unnamed: C801.1, R803.2, U801.1, U801.2 (-)
unnamed: C801.2, R801.1, R802.2
unnamed: C803.1, R803.1
unnamed: C804.1, R802.1, U801.3 (+)
unnamed: C806.1, R807.2, U801.6 (-), U801.7
unnamed: C806.2, R805.1, R806.2
unnamed: C807.1, R807.1
unnamed: C808.1, R806.1, U801.5 (+)
unnamed: C901.1, R903.2, U901.1, U901.2 (-)
unnamed: C901.2, R901.1, R902.2
unnamed: C903.1, R903.1
unnamed: C904.1, R902.1, U901.3 (+)
unnamed: C906.1, R907.2, U901.6 (-), U901.7
unnamed: C906.2, R905.1, R906.2
unnamed: C907.1, R907.1
unnamed: C908.1, R906.1, U901.5 (+)

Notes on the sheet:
Opamp e.g. LMV722, TLV272 dual-channel, rail-to-rail i/o, single-supply SOIC-8, validate pin compatibility
Test-purpose only capacitor, may improve 100kHz low-pass together with a 49k9Ohm resistor

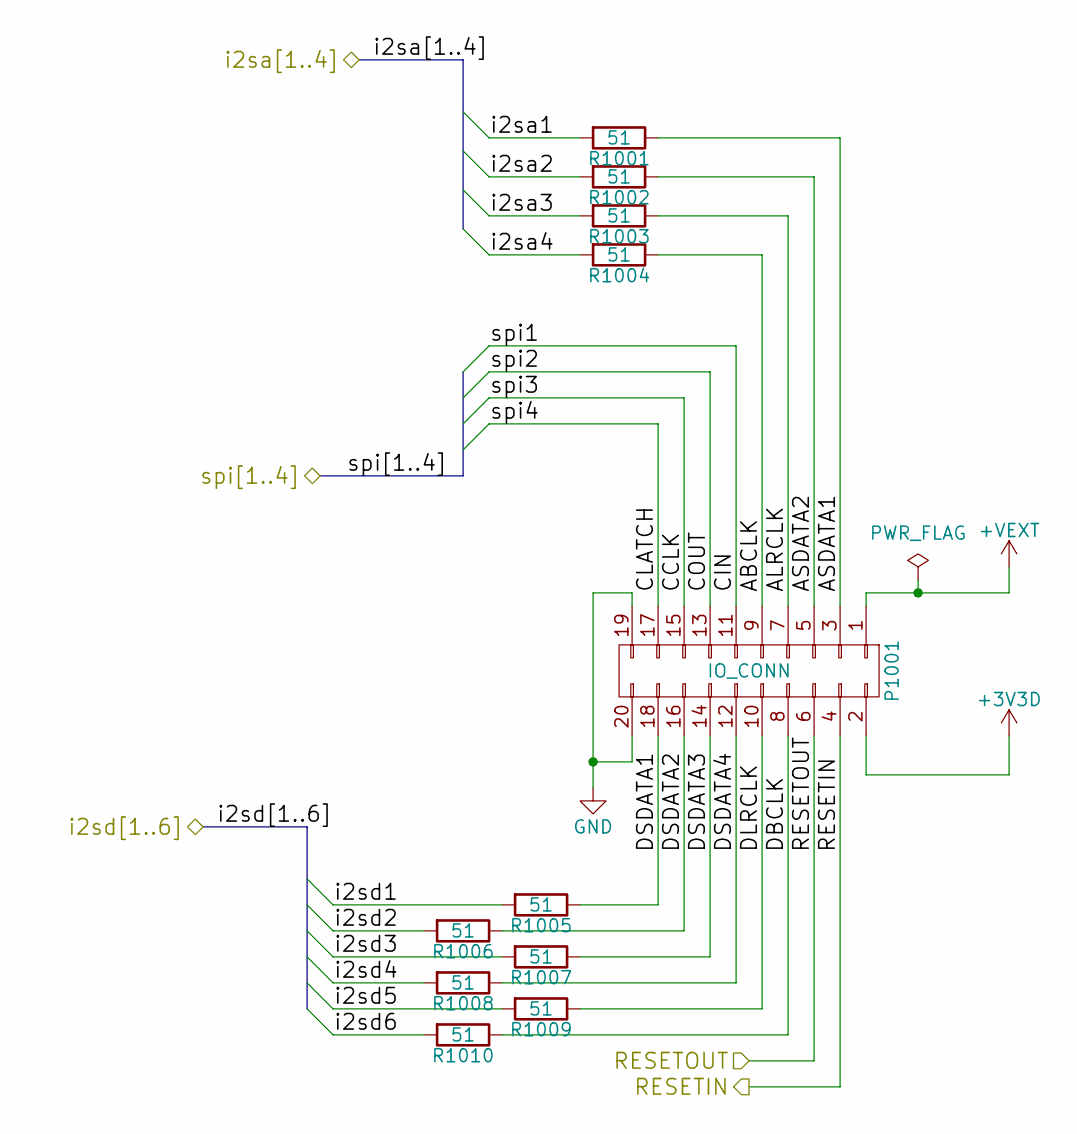
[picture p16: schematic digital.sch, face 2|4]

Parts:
P1001: IO_CONN; Pin_Header_Straight_2x10
R1001, R1002, R1003, R1004, R1005, R1006, R1007, R1008, R1009, R1010: 51; R_0603_HandSoldering

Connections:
+3V3D: P1001.2; also elsewhere on the board
+VEXT: P1001.1; also elsewhere on the board
/codec/digital-io/ABCLK: P1001.9, R1004.1
/codec/digital-io/ALRCLK: P1001.7, R1003.1
/codec/digital-io/ASDATA1: P1001.3, R1001.1
/codec/digital-io/ASDATA2: P1001.5, R1002.1
/codec/digital-io/DBCLK: P1001.8, R1010.1
/codec/digital-io/DLRCLK: P1001.10, R1009.1
/codec/digital-io/DSDATA1: P1001.18, R1005.1
/codec/digital-io/DSDATA2: P1001.16, R1006.1
/codec/digital-io/DSDATA3: P1001.14, R1007.1
/codec/digital-io/DSDATA4: P1001.12, R1008.1
/codec/digital-io/RESETIN: P1001.4; also elsewhere on the board
/codec/digital-io/RESETOUT: P1001.6; also elsewhere on the board
/codec/i2sa1: R1001.2; also elsewhere on the board
/codec/i2sa2: R1002.2; also elsewhere on the board
/codec/i2sa3: R1003.2; also elsewhere on the board
/codec/i2sa4: R1004.2; also elsewhere on the board
/codec/i2sd1: R1005.2; also elsewhere on the board
/codec/i2sd2: R1006.2; also elsewhere on the board
/codec/i2sd3: R1007.2; also elsewhere on the board
/codec/i2sd4: R1008.2; also elsewhere on the board
/codec/i2sd5: R1009.2; also elsewhere on the board
/codec/i2sd6: R1010.2; also elsewhere on the board
/codec/spi1: P1001.11; also elsewhere on the board
/codec/spi2: P1001.13; also elsewhere on the board
/codec/spi3: P1001.15; also elsewhere on the board
/codec/spi4: P1001.17; also elsewhere on the board
GND: P1001.19, P1001.20; also elsewhere on the board

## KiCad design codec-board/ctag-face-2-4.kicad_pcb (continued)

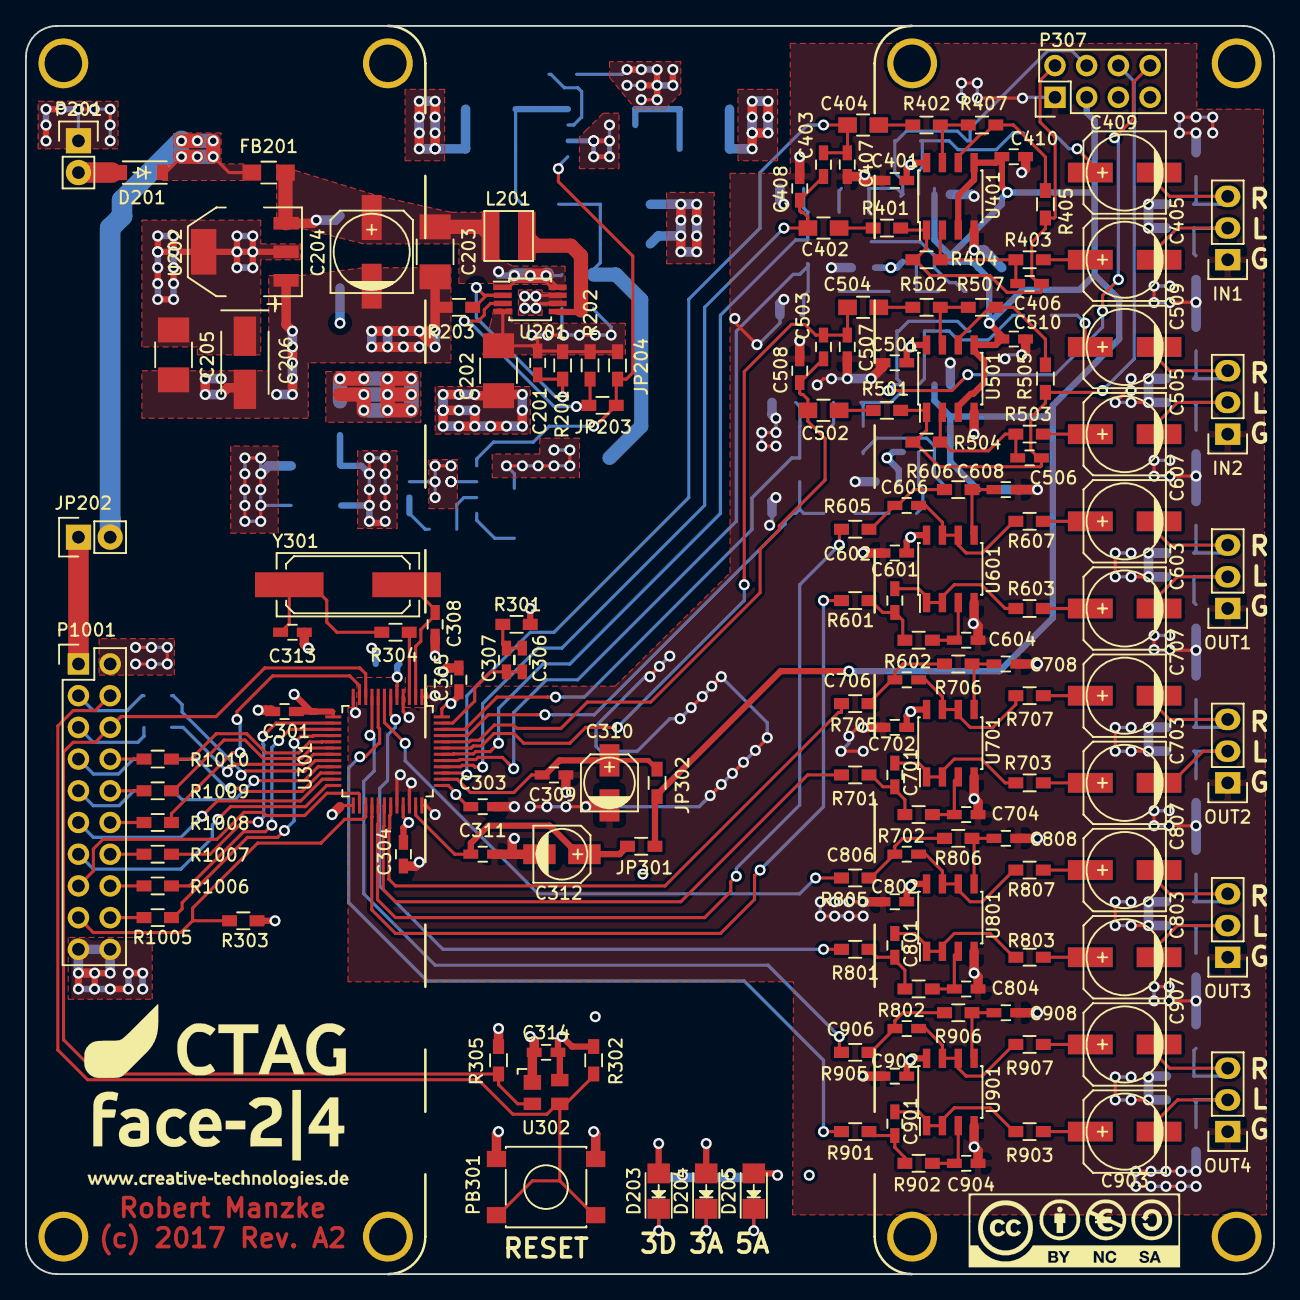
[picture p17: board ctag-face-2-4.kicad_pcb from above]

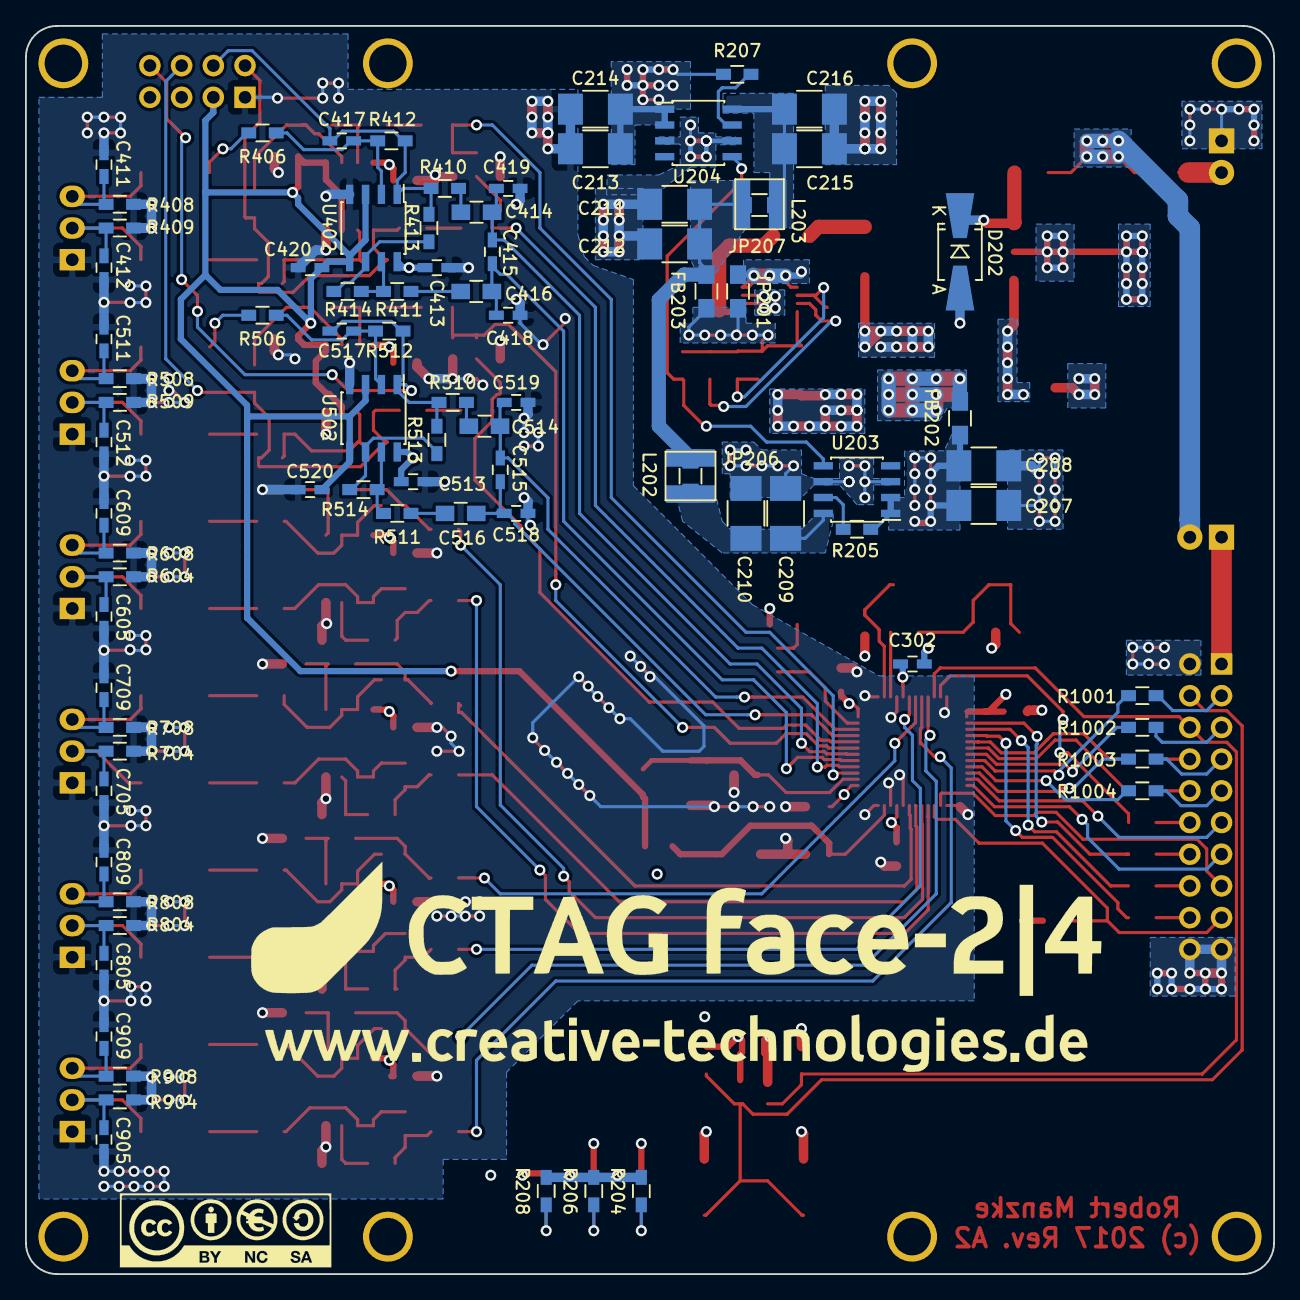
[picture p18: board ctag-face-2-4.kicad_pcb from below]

Board: 4 copper layers, 100.0 x 100.0 mm, 241 parts (84 on the bottom side), 143 nets.

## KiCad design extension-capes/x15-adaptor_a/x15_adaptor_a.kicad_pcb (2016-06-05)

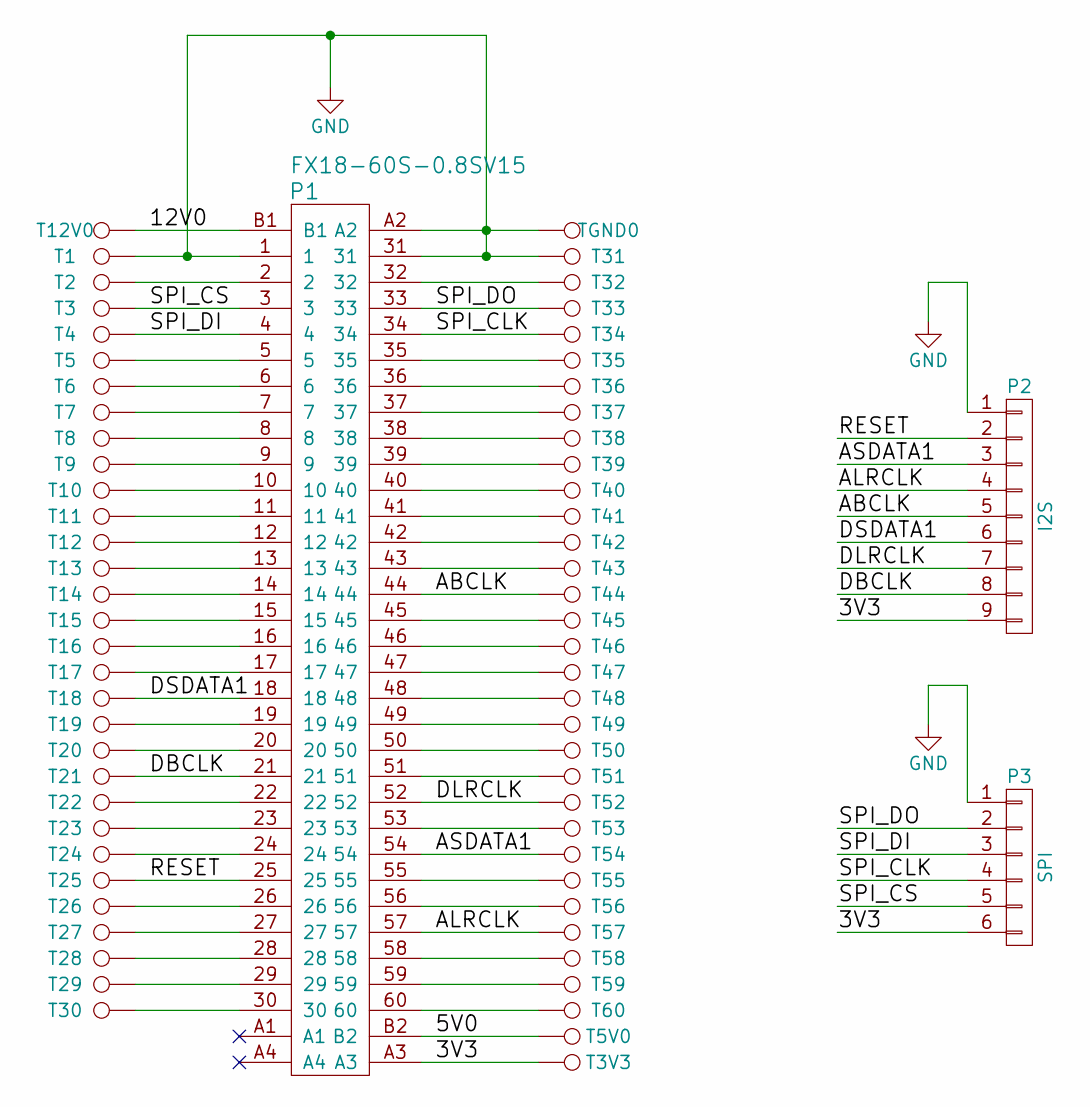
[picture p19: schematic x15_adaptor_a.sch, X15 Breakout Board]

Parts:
P1: FX18-60S-0.8SV15
P2: I2S; Pin_Header_Straight_1x09
P3: SPI; Pin_Header_Straight_1x06
T1, T2, T3, T3V3, T4, T5, T5V0, T6, T7, T8, T9, T10, T11, T12, T12V0, T13, T14, T15, T16, T17, T18, T19, T20, T21, T22, T23, T24, T25, T26, T27, T28, T29, T30, T31, T32, T33, T34, T35, T36, T37, T38, T39, T40, T41, T42, T43, T44, T45, T46, T47, T48, T49, T50, T51, T52, T53, T54, T55, T56, T57, T58, T59, T60: Testpin
TGND0: Testpin

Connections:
/3V3: P1.A3, P2.9, P3.6, T3V3.1
/5V0: P1.B2, T5V0.1
/12V0: P1.B1, T12V0.1
/ABCLK: P1.44, P2.5, T44.1
/ALRCLK: P1.57, P2.4, T57.1
/ASDATA1: P1.54, P2.3, T54.1
/DBCLK: P1.21, P2.8, T21.1
/DLRCLK: P1.52, P2.7, T52.1
/DSDATA1: P1.18, P2.6, T18.1
/RESET: P1.25, P2.2, T25.1
/SPI_CLK: P1.34, P3.4, T34.1
/SPI_CS: P1.3, P3.5, T3.1
/SPI_DI: P1.4, P3.3, T4.1
/SPI_DO: P1.33, P3.2, T33.1
GND: P1.1, P1.31, P1.A2, P2.1, P3.1, T1.1, T31.1, TGND0.1
unnamed: P1.2, T2.1
unnamed: P1.5, T5.1
unnamed: P1.6, T6.1
unnamed: P1.7, T7.1
unnamed: P1.8, T8.1
unnamed: P1.9, T9.1
unnamed: P1.10, T10.1
unnamed: P1.11, T11.1
unnamed: P1.12, T12.1
unnamed: P1.13, T13.1
unnamed: P1.14, T14.1
unnamed: P1.15, T15.1
unnamed: P1.16, T16.1
unnamed: P1.17, T17.1
unnamed: P1.19, T19.1
unnamed: P1.20, T20.1
unnamed: P1.22, T22.1
unnamed: P1.23, T23.1
unnamed: P1.24, T24.1
unnamed: P1.26, T26.1
unnamed: P1.27, T27.1
unnamed: P1.28, T28.1
unnamed: P1.29, T29.1
unnamed: P1.30, T30.1
unnamed: P1.32, T32.1
unnamed: P1.35, T35.1
unnamed: P1.36, T36.1
unnamed: P1.37, T37.1
unnamed: P1.38, T38.1
unnamed: P1.39, T39.1
unnamed: P1.40, T40.1
unnamed: P1.41, T41.1
unnamed: P1.42, T42.1
unnamed: P1.43, T43.1
unnamed: P1.45, T45.1
unnamed: P1.46, T46.1
unnamed: P1.47, T47.1
unnamed: P1.48, T48.1
unnamed: P1.49, T49.1
unnamed: P1.50, T50.1
unnamed: P1.51, T51.1
unnamed: P1.53, T53.1
unnamed: P1.55, T55.1
unnamed: P1.56, T56.1
unnamed: P1.58, T58.1
unnamed: P1.59, T59.1
unnamed: P1.60, T60.1

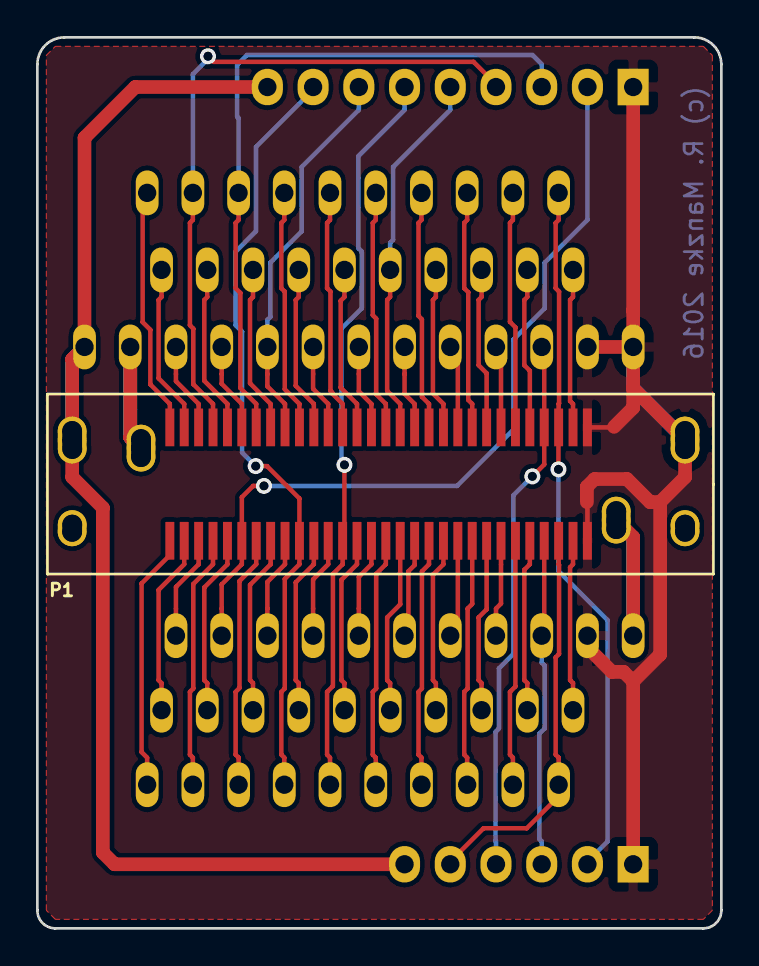
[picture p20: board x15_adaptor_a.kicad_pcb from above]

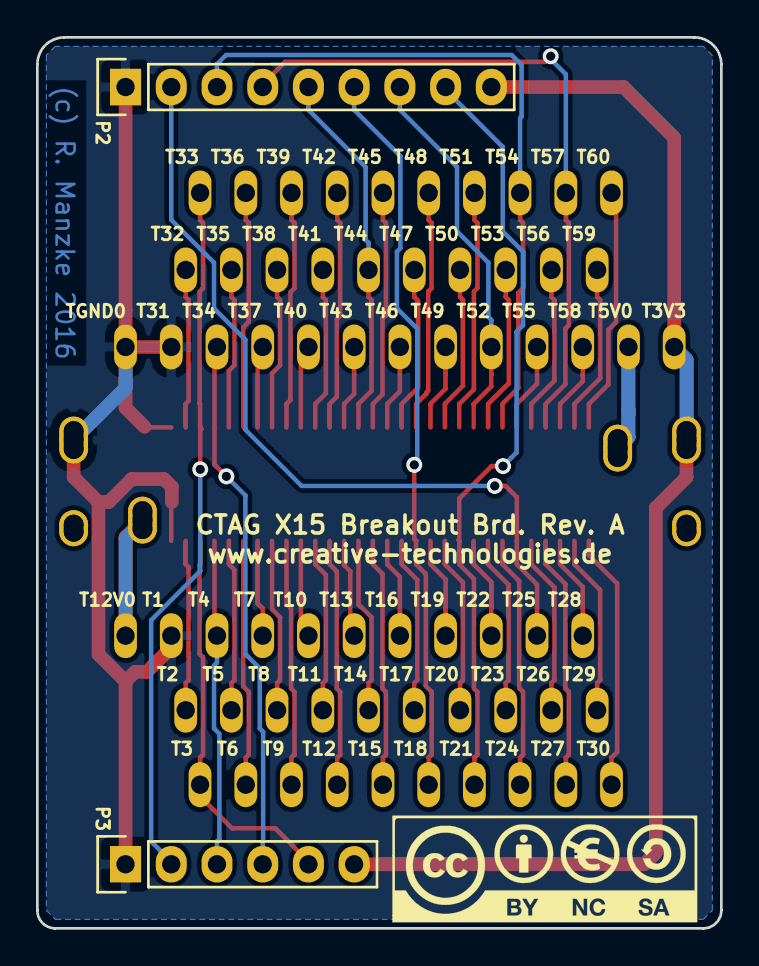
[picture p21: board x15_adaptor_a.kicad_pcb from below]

Board: 2 copper layers, 38.0 x 49.5 mm, 67 parts (66 on the bottom side), 62 nets.

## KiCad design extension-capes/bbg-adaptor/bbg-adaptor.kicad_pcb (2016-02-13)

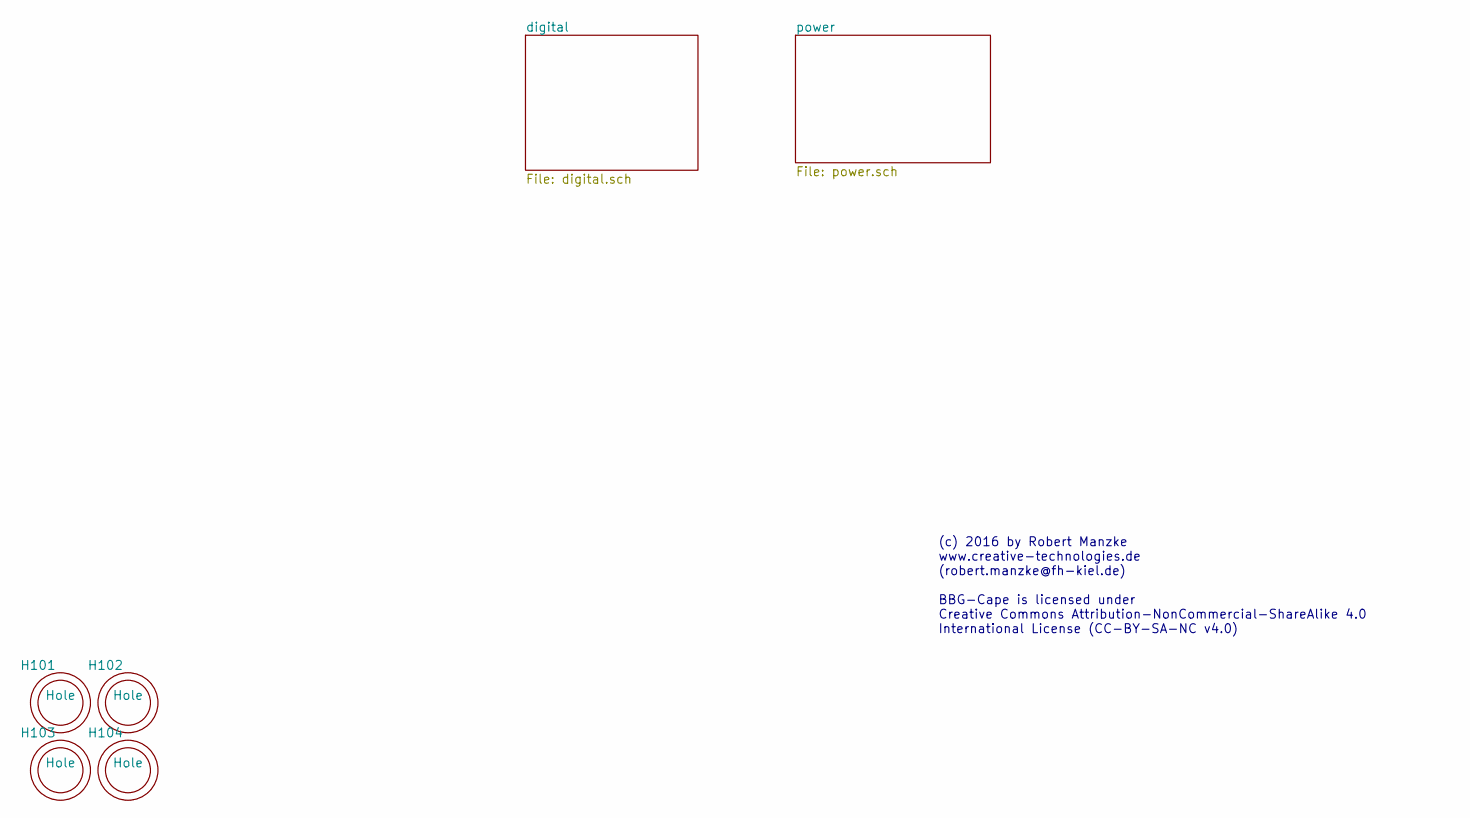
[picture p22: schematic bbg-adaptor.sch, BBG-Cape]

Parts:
H101, H102, H103, H104: Hole; Hole_3mm

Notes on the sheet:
(c) 2016 by Robert Manzke www.creative-technologies.de (robert.manzke@fh-kiel.de) BBG-Cape is licensed under Creative Commons Attribution-NonCommercial-ShareAlike 4.0 International License (CC-BY-SA-NC v4.0)


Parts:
C201, C202, C203, C204: C; C_1210_HandSoldering
CON201: BARREL_JACK; BARELL_CLIFF_DC10L
JP201, JP202, JP203: Jumper_NC_Small; R_0805_HandSoldering
L201: tbd; LPS4018
P201: CTRL; Pin_Header_Straight_1x01
P202: BBG_PWR; Pin_Header_Straight_1x02
P203: PWR; Pin_Header_Straight_1x02
U201: RS3-0505

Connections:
+5V: C203.1, C204.1, JP201.2, L201.2, P203.2
+VEXT: P202.2; also elsewhere on the board
GND: C201.2, C202.2, C203.2, C204.2, JP203.2, P203.1, U201.7 (VOUT-); also elsewhere on the board
GNDEXT: P202.1; also elsewhere on the board
unnamed: C201.1, C202.1, JP201.1, JP202.2, L201.1, U201.6 (VOUT+)
unnamed: CON201.1, JP203.1, U201.1 (VIN-)
unnamed: CON201.2, CON201.3, JP202.1, U201.2 (VIN+)
unnamed: P201.1, U201.3 (CTRL)

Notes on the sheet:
Use to bypass PI-Filter
Bypass DC/DC Converter


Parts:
C301, C302, C303, C304: 100n; C_0603_HandSoldering
JP301: Jumper_NC_Small; R_0603_HandSoldering
P301: BBG_CTRL; Pin_Header_Straight_2x06
P302: BBG_P9.20; Pin_Header_Straight_1x01
P303: BBG_P9.19; Pin_Header_Straight_1x01
P304: AD1938; Pin_Header_Straight_2x10
P305: BBG_DUMMY; Pin_Header_Straight_2x23
P307: BBG_P; Pin_Header_Straight_2x02
P308: BBG_I2S; Pin_Header_Straight_2x03
P309: BBG_P9.32; Pin_Header_Straight_1x01
P310: DSDATA2; Pin_Header_Straight_1x01
R301, R302, R303, R304, R305, R306, R307: 51; R_0603_HandSoldering
U301, U302: SI8662BC; SOIC-16_3.9x9.9mm_Pitch1.27mm

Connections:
+3V3D: C302.1, C304.1, P304.2, U301.16 (Vcc2), U302.1 (Vcc1)
+VEXT: C301.1, C303.1, U301.1 (Vcc1), U302.16 (Vcc2); also elsewhere on the board
/digital/ADCBCLK: P304.9, U301.10 (B6)
/digital/ADCLRCLK: P304.7, U302.4 (A3)
/digital/ASDATA1: P304.3, U302.5 (A4)
/digital/BBG_P9.11: P301.1, P307.1
/digital/BBG_P9.12: P301.2, R301.2
/digital/BBG_P9.13: P301.3, P307.3
/digital/BBG_P9.14: P301.4, P307.2
/digital/BBG_P9.15: P301.5, U301.5 (A4)
/digital/BBG_P9.16: P301.6, P307.4
/digital/BBG_P9.17: P301.7, U301.2 (A1)
/digital/BBG_P9.18: P301.8, U301.4 (A3)
/digital/BBG_P9.19: P301.9, P303.1
/digital/BBG_P9.21: P301.11, U301.6 (A5)
/digital/BBG_P9.22: P301.12, U301.3 (A2)
/digital/BBG_P9.27: P308.1, R304.2
/digital/BBG_P9.28: P308.2, R306.2
/digital/BBG_P9.29: P308.3, R302.2
/digital/BBG_P9.30: P308.4, R305.2
/digital/BBG_P9.31: P308.5, R303.2
/digital/CIN: P304.11, U301.13 (B3)
/digital/CLATCH: P304.17, U301.15 (B1)
/digital/CLK: P304.15, U301.14 (B2)
/digital/COUT: P304.13, U301.11 (B5)
/digital/DACBCLK: P304.8, U302.3 (A2)
/digital/DACLRCLK: P304.10, U302.2 (A1)
/digital/DSDATA1: P304.18, U302.6 (A5)
/digital/DSDATA2: P304.16, U302.7 (A6)
/digital/RESETIN: JP301.1, U301.12 (B4)
GND: C302.2, C304.2, P304.19, P304.20, U301.9 (GND2), U302.8 (GND1); also elsewhere on the board
GNDEXT: C301.2, C303.2, U301.8 (GND1), U302.9 (GND2); also elsewhere on the board
unnamed: JP301.2, P304.4
unnamed: P301.10, P302.1
unnamed: P308.6, P309.1
unnamed: P310.1, R307.2
unnamed: R301.1, U301.7 (A6)
unnamed: R302.1, U302.15 (B1)
unnamed: R303.1, U302.14 (B2)
unnamed: R304.1, U302.13 (B3)
unnamed: R305.1, U302.12 (B4)
unnamed: R306.1, U302.11 (B5)
unnamed: R307.1, U302.10 (B6)



Board: 2 copper layers, 43.1 x 100.0 mm, 39 parts (10 on the bottom side), 48 nets.

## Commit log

2015-11-03 Changed SW SPI pins due to collision with Bela
2015-11-03 added separate device tree overlays for 8 channel and 16 channel via software SPI
2015-11-03 Updated SW SPI pins
2015-11-03 bug fixes in device tree overlays for software SPI
2016-02-13 initial public
    [adc-stereo-buffer.sch, bbg-adaptor.kicad_pcb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]
2016-02-14 Added kernel compilation guide and pin connections table.
2016-02-27 Added device tree overlays
2016-06-01 added X15 breakout boards for testing, review stage
    [x15_adaptor_a.kicad_pcb, x15_adaptor_a.sch]
2016-06-02 x15 adaptor production stage
    [x15_adaptor_a-B.Cu.gbl, x15_adaptor_a-B.Mask.gbs, x15_adaptor_a-B.SilkS.gbo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]
2016-06-03 changed diameters of test pin holes
    [x15_adaptor_a-B.Cu.gbl, x15_adaptor_a-B.Mask.gbs, x15_adaptor_a-B.SilkS.gbo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]
2016-06-05 added multiple holes for oblong shape to account for boardhouse capabilities
    [x15_adaptor_a.kicad_pcb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]
2016-10-02 Added device tree overlay for SPI via GPIO (bitbanging)
2016-10-02 Updated device tree overlay for SW SPI
2016-10-12 Added SW SPI pin description
2016-12-12 updated device tree overlays for software SPI and daisy chained AD1938
2016-12-20 fixed bug in device tree overlays for software SPI and 16 channel daisy chain
2017-03-19 Added init.d scripts to load device tree overlays for CTAG face2|4 and CTAG Beast
2017-04-12 Added pin connections for BeagleBoard-X15
2017-04-18 added new pin connections for sw spi
2017-05-13 Added properties to configure bit delay of codec and McASP in device tree overlay.
2017-05-13 Removed spi-gpio from device tree overlay.
2017-06-04 changed page layout
    [adc-stereo-buffer.sch, codec.sch, ctag-face-2-4.sch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]
2017-06-04 fixed polarity bug on IN2
    [adc-stereo-buffer.sch, codec.sch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]
2017-06-04 finalized Rev A2
    [ctag-face-2-4.kicad_pcb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]
2017-11-13 Update Pin_Connections.md
    Removed McASP receive pin connections of CTAG face2|4 Rev. B
2021-11-07 Update KiCad link
    See https://forum.kicad.info/t/warning-avoid-all-links-to-kicad-pcb-org-use-kicad-org/31521/

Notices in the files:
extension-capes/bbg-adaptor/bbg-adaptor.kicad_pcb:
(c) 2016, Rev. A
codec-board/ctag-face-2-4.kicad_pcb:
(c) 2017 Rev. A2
